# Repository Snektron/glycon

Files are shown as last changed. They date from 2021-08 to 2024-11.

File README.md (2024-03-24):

nin# Glycon

## Dependencies

* meson
* ninja or samurai
* avr-binutils
* avr-gcc
* avr-libc

## Compiling

### Coprocessor

```
$ mkdir -p build/glyco
$ cd build/glyco
$ meson ../.. --cross-file ../../cross/avr-atmega2560-cross.ini
$ ninja
```

To use the provided `flash` target to flash the coprocessor, set the coprocessor port the arduino is connected with by passing `-Dport=/dev/<port>` to meson (usually /dev/ttyUSB0) and add yourself to to appropriate groups (typically `dialout` or `uucp`).

### Debugger

```
$ mkdir -p build/glydb
$ cd build/glydb
$ meson ../..
$ ninja
```

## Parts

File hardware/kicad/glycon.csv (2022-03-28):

Source: | /home/florian/projecten/glycon/doc/kicad/glycon.kicad_sch
Date: | za 26 mrt 2022 12:57:02 CET
Tool: | Eeschema (6.99.0-588-g9b3e9082d3)
Generator: | /usr/share/kicad/plugins/bom_csv_grouped_by_value.py
Component Count: | 53
Individual Components:
Item | Qty | Reference(s) | Value | LibPart | Footprint | Datasheet | Allied Price/Stock | Allied_Number | Description | Height | Manufacturer_Name | Manufacturer_Part_Number | Mouser Part Number | Mouser Price/Stock | RS Part Number | RS Price/Stock
 |  | C1 | 100nF | Device:C | Capacitor_THT:C_Disc_D4.7mm_W2.5mm_P5.00mm | ~
 |  | C2 | 100nF | Device:C | Capacitor_THT:C_Disc_D4.7mm_W2.5mm_P5.00mm | ~
 |  | C3 | 100nF | Device:C | Capacitor_THT:C_Disc_D4.7mm_W2.5mm_P5.00mm | ~
 |  | C4 | 100nF | Device:C | Capacitor_THT:C_Disc_D4.7mm_W2.5mm_P5.00mm | ~
 |  | C5 | 100nF | Device:C | Capacitor_THT:C_Disc_D4.7mm_W2.5mm_P5.00mm | ~
 |  | C6 | 100nF | Device:C | Capacitor_THT:C_Disc_D4.7mm_W2.5mm_P5.00mm | ~
 |  | C7 | 100nF | Device:C | Capacitor_THT:C_Disc_D4.7mm_W2.5mm_P5.00mm | ~
 |  | C8 | 100nF | Device:C | Capacitor_THT:C_Disc_D4.7mm_W2.5mm_P5.00mm | ~
 |  | C9 | 100nF | Device:C | Capacitor_THT:C_Disc_D4.7mm_W2.5mm_P5.00mm | ~
 |  | C10 | 100nF | Device:C | Capacitor_THT:C_Disc_D4.7mm_W2.5mm_P5.00mm | ~
 |  | C11 | 100nF | Device:C | Capacitor_THT:C_Disc_D4.7mm_W2.5mm_P5.00mm | ~
 |  | C12 | 100nF | Device:C | Capacitor_THT:C_Disc_D4.7mm_W2.5mm_P5.00mm | ~
 |  | C13 | 100nF | Device:C | Capacitor_THT:C_Disc_D4.7mm_W2.5mm_P5.00mm | ~
 |  | D1 | LED | Device:LED | LED_THT:LED_D5.0mm | ~
 |  | H1 | MountingHole_Pad | Mechanical:MountingHole_Pad | MountingHole:MountingHole_3.2mm_M3_Pad | ~
 |  | H2 | MountingHole_Pad | Mechanical:MountingHole_Pad | MountingHole:MountingHole_3.2mm_M3_Pad | ~
 |  | H3 | MountingHole_Pad | Mechanical:MountingHole_Pad | MountingHole:MountingHole_3.2mm_M3_Pad | ~
 |  | H4 | MountingHole_Pad | Mechanical:MountingHole_Pad | MountingHole:MountingHole_3.2mm_M3_Pad | ~
 |  | H5 | MountingHole_Pad | Mechanical:MountingHole_Pad | MountingHole:MountingHole_3.2mm_M3_Pad | ~
 |  | J1 | Arduino/system bus header | Connector_Generic:Conn_02x20_Odd_Even | Connector_PinSocket_2.54mm:PinSocket_2x20_P2.54mm_Vertical | ~
 |  | J2 | PMOD USBUART conn | Connector_Generic:Conn_01x06 | Connector_PinHeader_2.54mm:PinHeader_1x06_P2.54mm_Vertical | ~
 |  | J3 | Conn_01x02 | Connector_Generic:Conn_01x02 | Connector_PinHeader_2.54mm:PinHeader_1x02_P2.54mm_Vertical | ~
 |  | J4 | Conn_02x24_Odd_Even | Connector_Generic:Conn_02x24_Odd_Even | Connector_PinSocket_2.54mm:PinSocket_2x24_P2.54mm_Vertical | ~
 |  | Q1 | IRF9540N | Transistor_FET:IRF9540N | Package_TO_SOT_THT:TO-220-3_Vertical | http://www.irf.com/product-info/datasheets/data/irf9540n.pdf
 |  | Q2 | IRF9540N | Transistor_FET:IRF9540N | Package_TO_SOT_THT:TO-220-3_Vertical | http://www.irf.com/product-info/datasheets/data/irf9540n.pdf
 |  | R1 | 10K | Device:R | Resistor_THT:R_Axial_DIN0204_L3.6mm_D1.6mm_P5.08mm_Horizontal | ~
 |  | R2 | 10K | Device:R | Resistor_THT:R_Axial_DIN0204_L3.6mm_D1.6mm_P5.08mm_Horizontal | ~
 |  | R3 | 10K | Device:R | Resistor_THT:R_Axial_DIN0204_L3.6mm_D1.6mm_P5.08mm_Horizontal | ~
 |  | R4 | 10K | Device:R | Resistor_THT:R_Axial_DIN0204_L3.6mm_D1.6mm_P5.08mm_Horizontal | ~
 |  | R5 | 10K | Device:R | Resistor_THT:R_Axial_DIN0204_L3.6mm_D1.6mm_P5.08mm_Horizontal | ~
 |  | R6 | 10K | Device:R | Resistor_THT:R_Axial_DIN0204_L3.6mm_D1.6mm_P5.08mm_Horizontal | ~
 |  | R7 | 10K | Device:R | Resistor_THT:R_Axial_DIN0204_L3.6mm_D1.6mm_P5.08mm_Horizontal | ~
 |  | R8 | 1K | Device:R | Resistor_THT:R_Axial_DIN0204_L3.6mm_D1.6mm_P5.08mm_Horizontal | ~
 |  | R9 | 10K | Device:R | Resistor_THT:R_Axial_DIN0204_L3.6mm_D1.6mm_P5.08mm_Horizontal | ~
 |  | R10 | 10K | Device:R | Resistor_THT:R_Axial_DIN0204_L3.6mm_D1.6mm_P5.08mm_Horizontal | ~
 |  | R11 | 10K | Device:R | Resistor_THT:R_Axial_DIN0204_L3.6mm_D1.6mm_P5.08mm_Horizontal | ~
 |  | R12 | 470 | Device:R | Resistor_THT:R_Axial_DIN0204_L3.6mm_D1.6mm_P5.08mm_Horizontal | ~
 |  | SW1 | SW_Push | Switch:SW_Push | Button_Switch_THT:SW_PUSH_6mm | ~
 |  | SW2 | SW_Push | Switch:SW_Push | Button_Switch_THT:SW_PUSH_6mm | ~
 |  | U0 | Z80CPU | CPU:Z80CPU | Package_DIP:DIP-40_W15.24mm_Socket | www.zilog.com/manage_directlink.php?filepath=docs/z80/um0080
 |  | U1 | 628128_DIP32_SSOP32 | Memory_RAM:628128_DIP32_SSOP32 | Package_DIP:DIP-32_W15.24mm_Socket | http://www.futurlec.com/Datasheet/Memory/628128.pdf
 |  | U2 | SST39SF010 | Memory_Flash:SST39SF010 | Package_DIP:DIP-32_W15.24mm_Socket | http://ww1.microchip.com/downloads/en/DeviceDoc/25022B.pdf
 |  | U3 | 74HC32 | 74xx:74LS32 | Package_DIP:DIP-14_W7.62mm_Socket | http://www.ti.com/lit/gpn/sn74LS32
 |  | U4 | 74HC04 | 74xx:74HC04 | Package_DIP:DIP-14_W7.62mm_Socket | https://assets.nexperia.com/documents/data-sheet/74HC_HCT04.pdf
 |  | U5 | 74LS21 | 74xx:74LS21 | Package_DIP:DIP-14_W7.62mm_Socket | http://www.ti.com/lit/gpn/sn74LS21
 |  | U6 | 74LS139 | 74xx:74LS139 | Package_DIP:DIP-16_W7.62mm_Socket | http://www.ti.com/lit/ds/symlink/sn74ls139a.pdf
 |  | U7 | SIO0-DIP-40 | Zilog_Z80_Peripherals:SIO0-DIP-40 | Package_DIP:DIP-40_W15.24mm_Socket | http://www.zilog.com/docs/z80/ps0183.pdf | https://www.alliedelec.com/zilog-z84c4206peg/R1000052/ | R1000052 | Z80 CMOS SIO/0 Z84C40 Zilog | 4.06 | Zilog | Z84C4206PEG | 692-Z84C4206PEG | https://www.mouser.com/Search/Refine.aspx?Keyword=692-Z84C4206PEG | 6600766 | https://uk.rs-online.com/web/p/products/6600766
 |  | U8 | PIO-DIP-40 | Zilog_Z80_Peripherals:PIO-DIP-40 | Package_DIP:DIP-40_W15.24mm_Socket | https://www.zilog.com/appnotes_download.php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
 |  | U9 | 74HC244 | 74xx:74HC244 | Package_DIP:DIP-20_W7.62mm_Socket | https://assets.nexperia.com/documents/data-sheet/74HC_HCT244.pdf
 |  | U10 | 74HC244 | 74xx:74HC244 | Package_DIP:DIP-20_W7.62mm_Socket | https://assets.nexperia.com/documents/data-sheet/74HC_HCT244.pdf
 |  | U11 | PIO-DIP-40 | Zilog_Z80_Peripherals:PIO-DIP-40 | Package_DIP:DIP-40_W15.24mm_Socket | https://www.zilog.com/appnotes_download.php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
 |  | U12 | CTC-DIP-28 | Zilog_Z80_Peripherals:CTC-DIP-28 | Package_DIP:DIP-28_W15.24mm_Socket | http://www.zilog.com/docs/z80/ps0181.pdf |  |  | Z8430 Zilog CTC | 5.21 | Zilog | Z84C3010PEG | 692-Z84C3010PEG | https://www.mouser.com/Search/Refine.aspx?Keyword=692-Z84C3010PEG
 |  | X1 | ACO-6.144MHz | Oscillator:ACO-xxxMHz | Oscillator:Oscillator_DIP-14 | http://www.conwin.com/datasheets/cx/cx030.pdf
Collated Components:
Item | Qty | Reference(s) | Value | LibPart | Footprint | Datasheet | Allied Price/Stock | Allied_Number | Description | Height | Manufacturer_Name | Manufacturer_Part_Number | Mouser Part Number | Mouser Price/Stock | RS Part Number | RS Price/Stock
1 | 13 | C1, C2, C3, C4, C5, C6, C7, C8, C9, C10, C11, C12, C13 | 100nF | Device:C | Capacitor_THT:C_Disc_D4.7mm_W2.5mm_P5.00mm | ~
2 | 1 | D1 | LED | Device:LED | LED_THT:LED_D5.0mm | ~
3 | 5 | H1, H2, H3, H4, H5 | MountingHole_Pad | Mechanical:MountingHole_Pad | MountingHole:MountingHole_3.2mm_M3_Pad | ~
4 | 1 | J1 | Arduino/system bus header | Connector_Generic:Conn_02x20_Odd_Even | Connector_PinSocket_2.54mm:PinSocket_2x20_P2.54mm_Vertical | ~
5 | 1 | J2 | PMOD USBUART conn | Connector_Generic:Conn_01x06 | Connector_PinHeader_2.54mm:PinHeader_1x06_P2.54mm_Vertical | ~
6 | 1 | J3 | Conn_01x02 | Connector_Generic:Conn_01x02 | Connector_PinHeader_2.54mm:PinHeader_1x02_P2.54mm_Vertical | ~
7 | 1 | J4 | Conn_02x24_Odd_Even | Connector_Generic:Conn_02x24_Odd_Even | Connector_PinSocket_2.54mm:PinSocket_2x24_P2.54mm_Vertical | ~
8 | 2 | Q1, Q2 | IRF9540N | Transistor_FET:IRF9540N | Package_TO_SOT_THT:TO-220-3_Vertical | http://www.irf.com/product-info/datasheets/data/irf9540n.pdf
9 | 10 | R1, R2, R3, R4, R5, R6, R7, R9, R10, R11 | 10K | Device:R | Resistor_THT:R_Axial_DIN0204_L3.6mm_D1.6mm_P5.08mm_Horizontal | ~
10 | 1 | R8 | 1K | Device:R | Resistor_THT:R_Axial_DIN0204_L3.6mm_D1.6mm_P5.08mm_Horizontal | ~
11 | 1 | R12 | 470 | Device:R | Resistor_THT:R_Axial_DIN0204_L3.6mm_D1.6mm_P5.08mm_Horizontal | ~
12 | 2 | SW1, SW2 | SW_Push | Switch:SW_Push | Button_Switch_THT:SW_PUSH_6mm | ~
13 | 1 | U0 | Z80CPU | CPU:Z80CPU | Package_DIP:DIP-40_W15.24mm_Socket | www.zilog.com/manage_directlink.php?filepath=docs/z80/um0080
14 | 1 | U1 | 628128_DIP32_SSOP32 | Memory_RAM:628128_DIP32_SSOP32 | Package_DIP:DIP-32_W15.24mm_Socket | http://www.futurlec.com/Datasheet/Memory/628128.pdf
15 | 1 | U2 | SST39SF010 | Memory_Flash:SST39SF010 | Package_DIP:DIP-32_W15.24mm_Socket | http://ww1.microchip.com/downloads/en/DeviceDoc/25022B.pdf
16 | 1 | U3 | 74HC32 | 74xx:74LS32 | Package_DIP:DIP-14_W7.62mm_Socket | http://www.ti.com/lit/gpn/sn74LS32
17 | 1 | U4 | 74HC04 | 74xx:74HC04 | Package_DIP:DIP-14_W7.62mm_Socket | https://assets.nexperia.com/documents/data-sheet/74HC_HCT04.pdf
18 | 1 | U5 | 74LS21 | 74xx:74LS21 | Package_DIP:DIP-14_W7.62mm_Socket | http://www.ti.com/lit/gpn/sn74LS21
19 | 1 | U6 | 74LS139 | 74xx:74LS139 | Package_DIP:DIP-16_W7.62mm_Socket | http://www.ti.com/lit/ds/symlink/sn74ls139a.pdf
20 | 1 | U7 | SIO0-DIP-40 | Zilog_Z80_Peripherals:SIO0-DIP-40 | Package_DIP:DIP-40_W15.24mm_Socket | http://www.zilog.com/docs/z80/ps0183.pdf | https://www.alliedelec.com/zilog-z84c4206peg/R1000052/ | R1000052 | Z80 CMOS SIO/0 Z84C40 Zilog | 4.06 | Zilog | Z84C4206PEG | 692-Z84C4206PEG | https://www.mouser.com/Search/Refine.aspx?Keyword=692-Z84C4206PEG | 6600766 | https://uk.rs-online.com/web/p/products/6600766
21 | 2 | U8, U11 | PIO-DIP-40 | Zilog_Z80_Peripherals:PIO-DIP-40 | Package_DIP:DIP-40_W15.24mm_Socket | https://www.zilog.com/appnotes_download.php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
22 | 2 | U9, U10 | 74HC244 | 74xx:74HC244 | Package_DIP:DIP-20_W7.62mm_Socket | https://assets.nexperia.com/documents/data-sheet/74HC_HCT244.pdf
23 | 1 | U12 | CTC-DIP-28 | Zilog_Z80_Peripherals:CTC-DIP-28 | Package_DIP:DIP-28_W15.24mm_Socket | http://www.zilog.com/docs/z80/ps0181.pdf |  |  | Z8430 Zilog CTC | 5.21 | Zilog | Z84C3010PEG | 692-Z84C3010PEG | https://www.mouser.com/Search/Refine.aspx?Keyword=692-Z84C3010PEG
24 | 1 | X1 | ACO-6.144MHz | Oscillator:ACO-xxxMHz | Oscillator:Oscillator_DIP-14 | http://www.conwin.com/datasheets/cx/cx030.pdf

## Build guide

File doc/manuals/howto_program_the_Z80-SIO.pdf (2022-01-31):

Mario Blunk / electronics and IT engineering Buchfinkenweg 5
99102 Erfurt
Germany

cellular +49 (0)176 2904 5855 office phone +49 (0361) 5189 618
email | marioblunk@arcor.de
homepage | http://www.trainz.de (http://www.train-z.de/)

How To Program The Z80 Serial I/O (SIO) and CTC Document Version 2.1

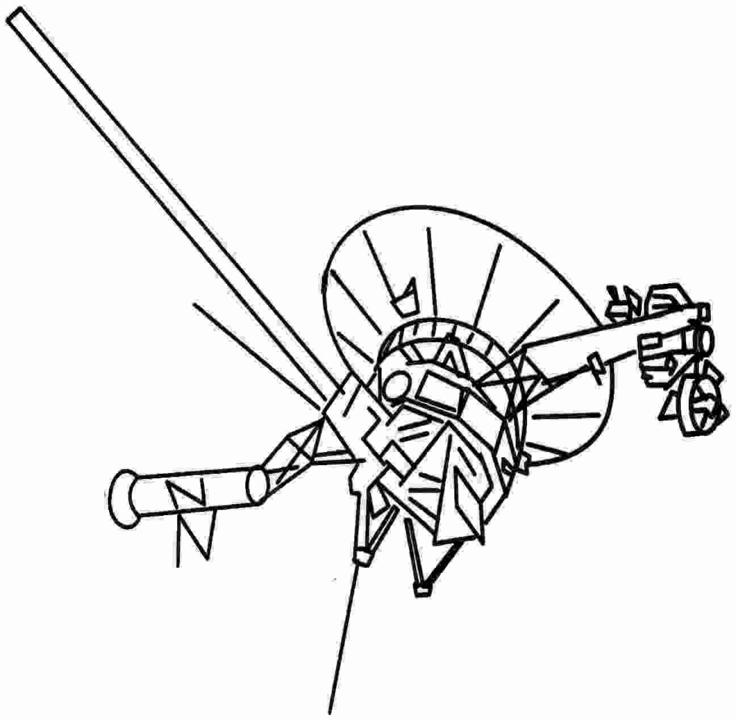
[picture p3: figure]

Date: 2010-03-31

## Contents

### Preface

The Z80 SIO is the most powerful I/O device of the Z80 product family. The official ZiLOG-datasheet gives a good overall view of all the features of this device but lacks a tutorial like approach and programming examples in assembly language.

This document aims to make the Z80 processor system popular again since a lot of valuable literature and expertise has vanished from the public because of more sophisticated processor architectures of the present.

Remarkably ZiLOG still produces the ICs of the Z80 family – since the late seventies !

Part one of this document describes how to program the SIO so that it communicates with a PC in asynchronous terminal mode whereas part two focuses on the block transfer mode used for file transmission. Also slightly touched in this document is the CTC programming and implementation of an interrupt mechanism.

There is no special focus on hardware issues like device selection, pin characteristics or ratings. Please refer to the official ZiLOG datasheets at www.zilog.com or www.z80.info .

The code examples shown here provide by far not the best performance and robustness. Therefore I appreciate every hint or critics to improve the quality of this document.

## 1 Terminal Mode

### 1.1 Desired Communication Mechanism

We want to program the SIO for asynchronous RS232 terminal mode with these parameters:
Baudrate: | 9600 Baud/sec
Stopbits: | 1
Startbits: | 1
Character length: 8 bit
Parity: none

In terminal mode the host computer (in our case the PC with any terminal program like Minicom or Hyper Terminal and an RS232 interface) communicates with the client (the Z80-SIO) character based via a so called Null-Modem-Cable. The host transmits one or more characters to the client, whereupon the client echoes this character back to the host and processes it. The host displays the echoed character on its screen. If the host does not “hear” the echoed character the communication is faulty.

Special attention is to be paid to the flow control scheme which is hardware based. In general this is called “RTSCTS” or just “hardware flow control”. This method allows transmission of all 8-bitcharacters (so called binary mode) and prevents overrunning of one of the peers in case on of them is to slow. In this document I assume the host PC is much faster than the client.
The wiring of the null modem cable used here has following connections between its female 9 pin D-Sub connectors:
1 – 4 / 4-1 | cross wired DTR and DCD
2 – 3 / 3 – 2 | cross wired TxD and RxD
5 – 5 | signal ground (GND)
7 – 8 / 8 – 7 | cross wird RTC and CTS
9 – 9 | ring indicator (RI, not used here)

### 1.2 SIO Device Structure and external wiring

Figure 1 shows the block diagram of the device with the blocks and signals needed for our example outlined in red. Figure 2 shows the data paths within the SIO. Marked in red are the blocks we need for asynchronous mode.

### 1.2.1 Wiring

Data and control: | These are the Z80 bus signals D[7:0], A[1:0], /RD, /IOREQ,
/RESET, /CE and CLK.

Interrupt Control Lines: /M1, /INT connected to CPU, IEI and IEO daisy chained to other periphery

Serial Data: | TxD and RxD going towards host computer¹
Channel Clocks: | TxCA and RxCA driven by CTC channel output TO0

Modem or other Controls: CTS, RTS, DTR, DCD used for hardware flow control

miscellaneous: | /SYNC not used, pulled high by 10k resistor
/Wait/Ready comes out of the device. It is to be connected to the WAIT-Input of the Z80-CPU. By asserting this signal the SIO tells the CPU to wait until the SIO has completed a character transfer. For this example we do not make use of this connection.

1 Usually these signals are not connected directly to the host but via diver devices like MAX232, 1488, 1489 or similar level converters.

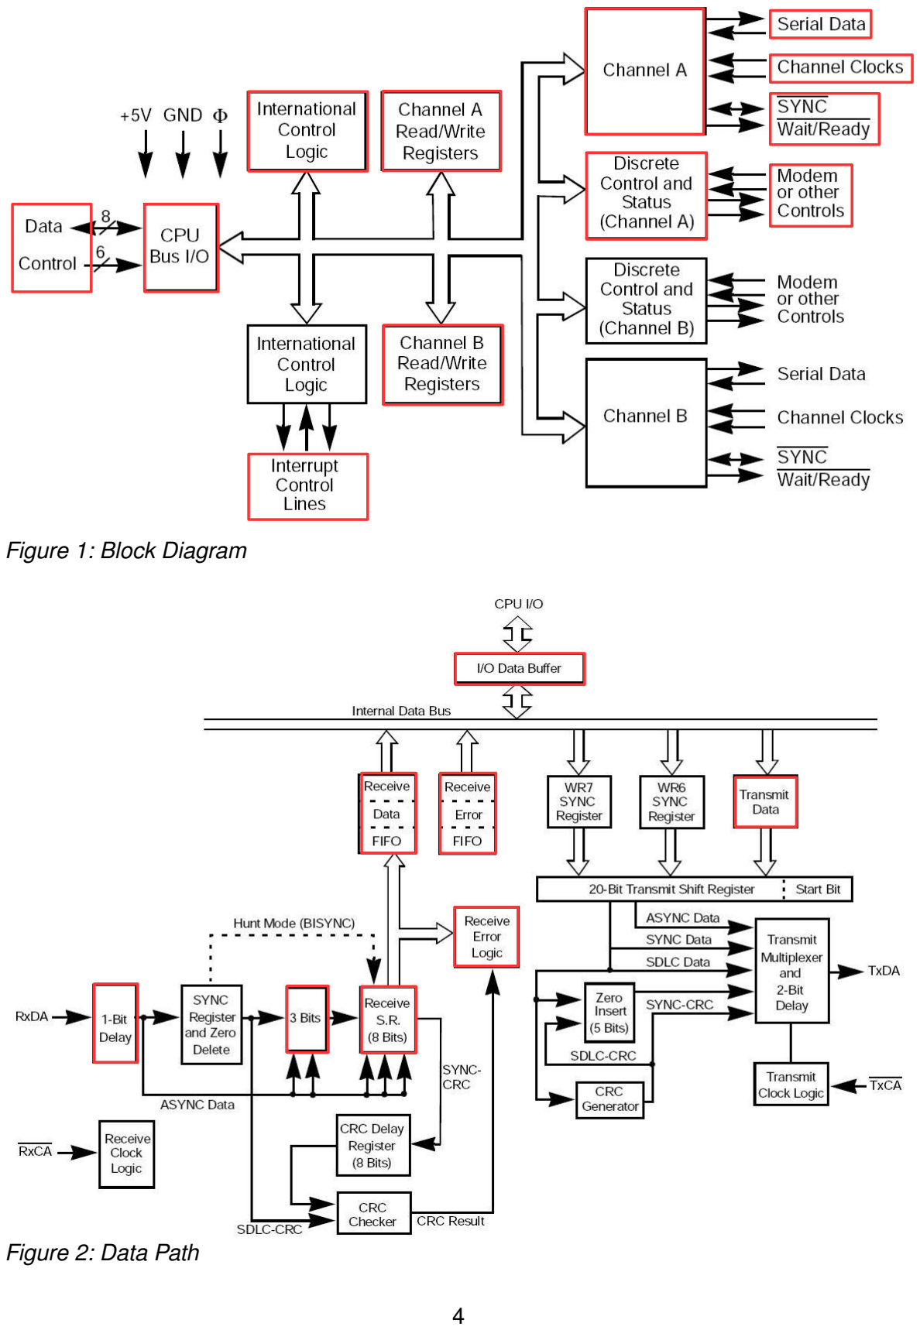
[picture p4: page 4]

Figure 1: Block Diagram

Figure 2: Data Path

### 1.3 Programming

Tree problems have to be solved: initializing the SIO, implementing the interrupt mechanism, echoing the received character, transmitting a character and turning on/off the SIO RX-channel in certain situations.

### 1.3.1 Header

The header show below defines the hardware addresses of the data and control port of your SIO and the address of your CTC channel 0. My hardware here uses the addresses 0x4, 0x6 and 0x0.

### 1.3.2 Interrupt Vector Table

Every time the SIO receives a character it requests an interrupt causing the CPU to jump to the memory address specified by the term RX_CHA_AVAILABLE. Special receive conditions like receiver buffer overrun cause a jump to location SPEC_RX_CONDITION.

Text 1: header

SIO_A_D | equ | 4h
SIO_A_C | equ | 6h
CH0 | equ | 0h

Text 2: SIO interrupt vector table

INT_VEC:
org | 0Ch
DEFW | RX_CHA_AVAILABLE
org | 0Eh
DEFW | SPEC_RX_CONDITON

### 1.3.3 Initializing the SIO

First we have to configure the SIO using the sequence shown in Text 3. For detailed information on the purpose of certain registers and control bits please read the SIO datasheet. We operate the SIO in interrupt mode “interrupt on all received characters”.

Text 3: configure the SIO

SIO_A_RESET:
;set up TX and RX:
ld | a,00110000b | ;write into WR0: error reset, select WR0
out | (SIO_A_C),A
ld | a,018h | ;write into WR0: channel reset
out | (SIO_A_C),A
ld | a,004h | ;write into WR0: select WR4
out | (SIO_A_C),A
ld | a,44h | ;44h write into WR4: clkx16,1 stop bit, no parity
out | (SIO_A_C),A
ld | a,005h | ;write into WR0: select WR5
out | (SIO_A_C),A
ld | a,0E8h | ;DTR active, TX 8bit, BREAK off, TX on, RTS inactive
out | (SIO_A_C),A
ld | a,01h | ;write into WR0: select WR1
out | (SIO_B_C),A
ld | a,00000100b | ;no interrupt in CH B, special RX condition affects vect
out | (SIO_B_C),A
ld | a,02h | ;write into WR0: select WR2
out | (SIO_B_C),A
ld | a,0h | ;write into WR2: cmd line int vect (see int vec table)
| | ;bits D3,D2,D1 are changed according to RX condition
out | (SIO_B_C),A
ld | a,01h | ;write into WR0: select WR1
out | (SIO_A_C),A
ld | a,00011000b | ;interrupt on all RX characters, parity is not a spec RX condition
| | ;buffer overrun is a spec RX condition
out | (SIO_A_C),A

SIO_A_EI:
;enable SIO channel A RX
ld | a,003h | ;write into WR0: select WR3
out | (SIO_A_C),A
ld | a,0C1h | ;RX 8bit, auto enable off, RX on
out | (SIO_A_C),A
;Channel A RX active
RET

### 1.3.4 Initializing the CTC

The CTC channel 0 provides the receive and transmit clock for the SIO.

### 1.3.5 Initializing the CPU

The CPU is to run in interrupt mode 2. See Text 5 below. This has to be done after initializing SIO and CTC.

Text 5: set up the CPU interrupt mode 2

INT_INI:
ld | A,0
ld | I,A | ;load I reg with zero
im | 2 | ;set int mode 2
ei | | ;enable interupt

Text 4: configuring the CTC channel 0

INI_CTC:

;init CH0
;CH0 provides SIO A RX/TX clock
ld | A,00000111b | ; int off, timer on, prescaler=16, don't care ext. TRG edge,
| | ; start timer on loading constant, time constant follows
| | ; swrst active, this is a ctrl cmd
out | (CH0),A
ld | A,2h | ; time constant defined
out | (CH0),A | ; and loaded into channel 0
| | ; TO0 outputs frequency=CLK/2/16/(time constant)/2
| | ; which results in 9600 bits per sec

### 1.3.6 Hardware Flow Control

In order to signal the host whether the client is ready or not to receive a character the RTS line coming out of the client (and driving towards the host) needs to be switched. As earlier said I assume the host is much faster than the client, that why I do not implement a routine to check the CTS-line coming from the host.

### 1.3.7 Disabling SIO RX-channel

When certain conditions arise it might by important to disable the receive channel of the SIO (see routine in Text 7).

Text 6: signaling the host go or nogo for reception

A_RTS_OFF:
ld | a,005h | ;write into WR0: select WR5
out | (SIO_A_C),A
ld | a,0E8h | ;DTR active, TX 8bit, BREAK off, TX on, RTS inactive
out | (SIO_A_C),A
ret

A_RTS_ON:
ld | a,005h | ;write into WR0: select WR5
out | (SIO_A_C),A
ld | a,0EAh | ;DTR active, TX 8bit, BREAK off, TX on, RTS active
out | (SIO_A_C),A
ret

Text 7: Disabling the SIO

SIO_A_DI:
;disable SIO channel A RX
ld | a,003h | ;write into WR0: select WR3
out | (SIO_A_C),A
ld | a,0C0h | ;RX 8bit, auto enable off, RX off
out | (SIO_A_C),A
;Channel A RX inactive
ret

### 1.3.8 Interrupt Service Routines

Upon reception of a character the routine RX_CHA_AVAILABLE shown in Text 8 is executed. Here you get the character set by the host. In the end of this routine, the character is sent back to the host by a simple single command
out (SIO_A_D),A
Note: In this example we backup only register AF. Depending on your application you might be required to backup more registers like HL, DE, CD, ...
Routine SPEC_RX_CONDITION is executed upon a special receive condition like buffer overrun. In my example the CPU is to jump at the warmstart location 0x0000.

Note: The code written in red might be required if you want the CPU to be ready for another interrupt (ei) and to give the host a go for another transmission (call A_RTS_ON). I recommend to put these two lines not here but in your main program routine that processes the characters received by the SIO. This way you process one character after another and avoid overrunning your SIO RX buffer.

Text 8: character received routine

RX_CHA_AVAILABLE:

push | AF | ;backup AF
call | A_RTS_OFF
in | A,(SIO_A_D) | ;read RX character into A

; A holds received character

;do something with the received character

;echo character to host
out | (SIO_A_D),A
call | TX_EMP
ei | | ;see comments below
call | A_RTS_ON | ;see comments below
pop | AF | ;restore AF
Reti

SPEC_RX_CONDITON:
jp 0000h

### 1.3.9 Transmission of a character to the host

In general transmitting of a character is done by the single command
out (SIO_A_D),A
as written in Text 8. To make sure the character has been sent completely the transmit buffer needs to be checked if it is empty. The general routine to achieve this is shown in Text 9.

Text 9: transmitting a character to host

TX_EMP:
; check for TX buffer empty
sub | a | ;clear a, write into WR0: select RR0
inc | a | ;select RR1
out | (SIO_A_C),A
in | A,(SIO_A_C) | ;read RRx
bit | 0,A
jp | z,TX_EMP
ret

## 2 File Transfer Mode

### 2.1 Desired Communication Mechanism

We want to program the SIO for asynchronous RS232 X-Modem protocol with these parameters:

Baudrate: | 9600 Baud/sec
Stopbits: | 1
Startbits: | 1
Character length: 8 bit
Parity: none

In difference to the character based mode described in part 1 (Terminal Mode) blocks of 128 byte size are to be transferred over the Null-Modem-Cable from the host PC to the client, the Z80-machine. I choose the X-Modem protocol due to its robustness and easy feasibility. Typical terminal programs like HyperTerminal, Kermit or Minicom do support the X-Modem protocol.
Of course you can also transfer a file via character based mode but the transfer will take much more time.
Regarding the device structure, Null-Modem-Cable, wiring and flowcontrol please refer to section 1.1 on page 2 and 1.2 on page 3.

A web link to the description of the X-Modem protocol can be found in section 4 on page 19.

Note: For this mode the connection of the CPU pin /WAIT and the SIO pin /Wait/Ready is required. Please see section 1.2.1 on page 3.

### 2.2 Programming

Four problems have to be solved: initializing the SIO, implementing the interrupt mechanism, requesting the host to start the X-Modem transfer and load the file to a certain RAM location.

### 2.2.1 Header

The header show below defines the hardware addresses of the data and control port of your SIO and the address of your CTC channel 0. My hardware here uses the addresses 0x4, 0x6 and 0x0. Further on there is a RAM locations defined for counting bad blocks while the file is being transferred.

### 2.2.2 Interrupt Vector Table

Every time the SIO receives the first byte of a block it requests an interrupt causing the CPU to jump to the memory address specified by the term BYTE_AVAILABLE. This is the interrupt mode: interrupt on first character. Special receive conditions like receiver buffer overrun cause a jump to location SPEC_BYTE_COND. The latter case aborts the transfer.

### 2.2.3 Initializing the CTC

Please read section 1.3.4 on page 7.

Text 10: header

SIO_A_D | equ | 4h
SIO_A_C | equ | 6h
CH0 | equ | 0h
temp0 | equ | 1015h ;holds number of
| | ;unsuccessful block transfers/block during download

Text 11: SIO interrupt vector table

INT_VEC:
org | 1Ch
DEFW | BYTE_AVAILABLE
org | 1Eh
DEFW | SPEC_BYTE_COND

### 2.2.4 Initializing the CPU

Please read section 1.3.5 on page 7.

### 2.2.5 X-Modem File Transfer

The assembly code of this module is described in the following sections. Due to its complexity I split it into parts shown in Text 12, 13 and 14 whose succession must not be mixed. For detailed information on the purpose of certain registers and control bits please read the SIO datasheet.

### 2.2.5.1 Host triggered transfer and setup

The host PC initiates the transfer. Using Minicom for example you press CTRL-A-S to get into a menu where you select the xmodem protocol and afterward into the file menu to select the file to be sent to the client. The procedure is similar with HyperTerminal.
After that the host waits for a NAK character sent by the client.
Now you should run the code shown below in Text 12 on your Z80-machine. This code initializes the SIO for interrupt mode “interrupt on first received character”.

;set up TX and RX:

ld | a,018h | ;write into WR0: channel reset
out | (SIO_A_C),A
ld | a,004h | ;write into WR0: select WR4
out | (SIO_A_C),A
ld | a,44h | ;44h write into WR4: clkx16,1 stop bit, no parity
out | (SIO_A_C),A
ld | a,005h | ;write into WR0: select WR5
out | (SIO_A_C),A
ld | a,0E8h | ;DTR active, TX 8bit, BREAK off, TX on, RTS inactive
out | (SIO_A_C),A
ld | a,01h | ;write into WR0: select WR1
out | (SIO_B_C),A
ld | a,00000100b | ;no interrupt in CH B, special RX condition affects vect
out | (SIO_B_C),A
ld | a,02h | ;write into WR0: select WR2
out | (SIO_B_C),A
ld | a,10h | ;write into WR2: cmd line int vect (see int vec table)
out | (SIO_B_C),A | ;bits D3,D2,D1 are changed according to RX condition

Text 12: setup 1

Now we do some settings for bad block counting, the first block number to expect and the RAM destination address of the file to receive from the host. See Text 13. The destination address setting is red colored. From this RAM location onwards the file is to be stored. Im my example I use address 0x8000. Depending on your application you should change this value.

Text 14 shows the code section that prepares the CPU for the reception of the first byte of a data block. The line colored red makes the CPU waiting for an interrupt which is caused by the SIO. The belonging interrupt service routine is shown in Text 15.
Once a block has been received, the checksum is verified and possible bad blocks counted. The same data block is transferred maximal 10 times whereupon the transfer is aborted.
sub | A
ld | (temp0),A | ;reset bad blocks counter
ld | C,1h | ;C holds first block nr to expect
ld | HL,8000h | ;set lower destination address of file
call | SIO_A_EI
call | A_RTS_ON
call | TX_NAK | ;NAK indicates ready for transmission to host

Text 13: setup 2

REC_BLOCK:

;set block transfer mode
ld | a,21h | ;write into WR0 cmd4 and select WR1
out | (SIO_A_C),A
ld | a,10101000b | ;wait active, interrupt on first RX character
out | (SIO_A_C),A | ;buffer overrun is a spec RX condition

ei
call | A_RTS_ON
halt | | ;await first rx char
call | A_RTS_OFF
ld | a,01h | ;write into WR0: select WR1
out | (SIO_A_C),A
ld | a,00101000b | ;wait function inactive
out | (SIO_A_C),A

;check return code of block reception (e holds return code)
ld | a,e
cp | 0 | ;block finished, no error
jp | z,l_210
cp | 2 | ;eot found
jp | z,l_211
cp | 3 | ;chk sum error
jp | z,l_613
ld | a,10h
jp | l_612
l_210: call | TX_ACK | ;when no error
inc | c | ;prepare next block to receive
sub | A
ld | (temp0),A | ;clear bad block counter
jp | REC_BLOCK
l_211: call | TX_ACK | ;on eot
ld | A,01h
jp | l_612
l_613: call | TX_NAK | ;on chk sum error
scf
ccf | | ;clear carry flag
ld | DE,0080h | ;subtract 80h
sbc | HL,DE | ;from HL, so HL is reset to block start address
ld | A,(temp0) | ;count bad blocks in temp0
inc | A
ld | (temp0),A
cp | 09h
jp | z,l_612 | ;abort download after 9 attempts to transfer a block
jp | REC_BLOCK | ;repeat block reception

l_612:
DLD_END:

ret

Text 14: Receive Data Block

BYTE_AVAILABLE:

EXP_SOH_EOT:
| in | A,(SIO_A_D) | ;read RX byte into A
l_205: cp | 01h | ;check for SOH
| jp | z,EXP_BLK_NR
| cp | 04h | ;check for EOT
| jp | nz,l_2020
| ld | e,2h
| reti

;await block number
EXP_BLK_NR:
| in | A,(SIO_A_D) | ;read RX byte into A
| cp | C | ;check for match of block nr
| jp | nz,l_2020

;await complement of block number
| ld | A,C | ;copy block nr to expect into A
| CPL | | ;and cpl A
| ld | E,A | ;E holds cpl of block nr to expect

EXP_CPL_BLK_NR:
| in | A,(SIO_A_D) | ;read RX byte into A
| cp | E | ;check for cpl of block nr
| jp | nz,l_2020

;await data block
| ld | D,0h | ;start value of checksum
| ld | B,80h | ;defines block size 128byte

EXP_DATA:
| in | A,(SIO_A_D) | ;read RX byte into A
| ld | (HL),A
| add | A,D | ;update
| ld | D,A | ;checksum in D
| inc | HL | ;dest address +1
| djnz | EXP_DATA | ;loop until block finished

EXP_CHK_SUM:
| in | A,(SIO_A_D) | ;read RX byte into A
; | ld | a,045h | ;for debug only
| cp | D | ;check for checksum match
| jp | z,l_2021
| ld | e,3h
| reti
l_2020: ld | E,1h
| RETI
l_2021: ld | E,0h
| RETI | | ;return when block received completely

;-Int routine on RX overflow

SPEC_BYTE_COND: | ;in case of RX overflow prepare abort of transfer
| ld | HL,DLD_END
| push | HL
| reti

Text 15: Interrupt Service Routine

### 2.2.5.2 Subroutines

Important for the X-Modem protocol is the sending of the Acknowledge and the Not-Acknowledge character to the host machine. For all other routines used in the code above please refer to sections 1.3.3 on page 6 and 1.3.6 on page 8.

TX_NAK:
ld | a,15h | ;send NAK 15h to host
out | (SIO_A_D),A
call | TX_EMP
RET

TX_ACK:
ld | a,6h | ;send AK to host
out | (SIO_A_D),A
call | TX_EMP
RET

Text 16: Acknowledge / Not-Acknowledge

## 3 Z80 IC equivalents table

An overview of ICs of the famous Z80 family gives Table 1.

device | equivalent type
Z80-CPU | BU18400A-PS (ROHM) D780C-1(NEC) KP1858BM1/2/3 / KR1858BM1/2/3 (USSR) LH0080 (Sharp) MK3880x (Mostek) T34VM1 / T34BM1 (USSR) TMPZ84C00AP-8 (Toshiba) UA880 / UB880 / VB880D (MME) Z0840004 (ZiLOG) Z0840006 (ZiLOG) Z80ACPUD1 (SGS-Ates) Z84C00AB6 (SGS-Thomson) Z84C00 (ZiLOG) Z8400A (Goldstar) U84C00 (MME)
Z80-SIO | UA8560 , UB8560 (MME) Z0844004 (ZiLOG) Z8440AB1 (ST) Z0844006 (ZiLOG) Z84C40 (ZiLOG) U84C40 (MME)
Z80-PIO | Z0842004/6 (ZiLOG) UA855 / UB855 (MME) Z84C20 (ZiLOG) U84C20 (MME)
Z80-CTC | Z84C30 (ZiLOG) U84C30 (MME) UA857 / UB857 (MME)

Table 1: Z80 equivalents

## 4 Useful Links

A complete embedded Z80 system can be found at http://www.trainz.de/trainz (http://www.train-z.de/train-z)

The Free and Open Productivity Suite OpenOffice at http://www.openoffice.org Z80 assembler for Linux and UNIX at http://www.unix4fun.org/z80pack/
The powerful communication tool Kermit at http://www.columbia.edu/kermit/ The Z80 history at http://en.wikipedia.org/wiki/Zilog_Z80
The X-Modem Protocol Reference
at http://www.trainz. de/trainz/pdf/xymodem.pdf (http://www.trainz.de/trainz/pdf/xymodem.pdf)

EAGLE an affordable and very efficient schematics and layout tool at http://www.cadsoftusa.com/

## 5 Further Reading

I recommend to read these books:

“Using C-Kermit” / Frank da Cruz, Christine M. Gianone /
ISBN 1-55558-108-0 (english)
“C-Kermit : Einführung und Referenz” / Frank da Cruz, Christine M. Gianone / ISBN 3-88229-023-4 (german)

## 6 Disclaimer

This tutorial is believed to be accurate and reliable. I do not assume responsibility for any errors which may appear in this document. I reserve the right to change it at any time without notice, and do not make any commitment to update the information contained herein.
My Boss is a Jewish Carpenter

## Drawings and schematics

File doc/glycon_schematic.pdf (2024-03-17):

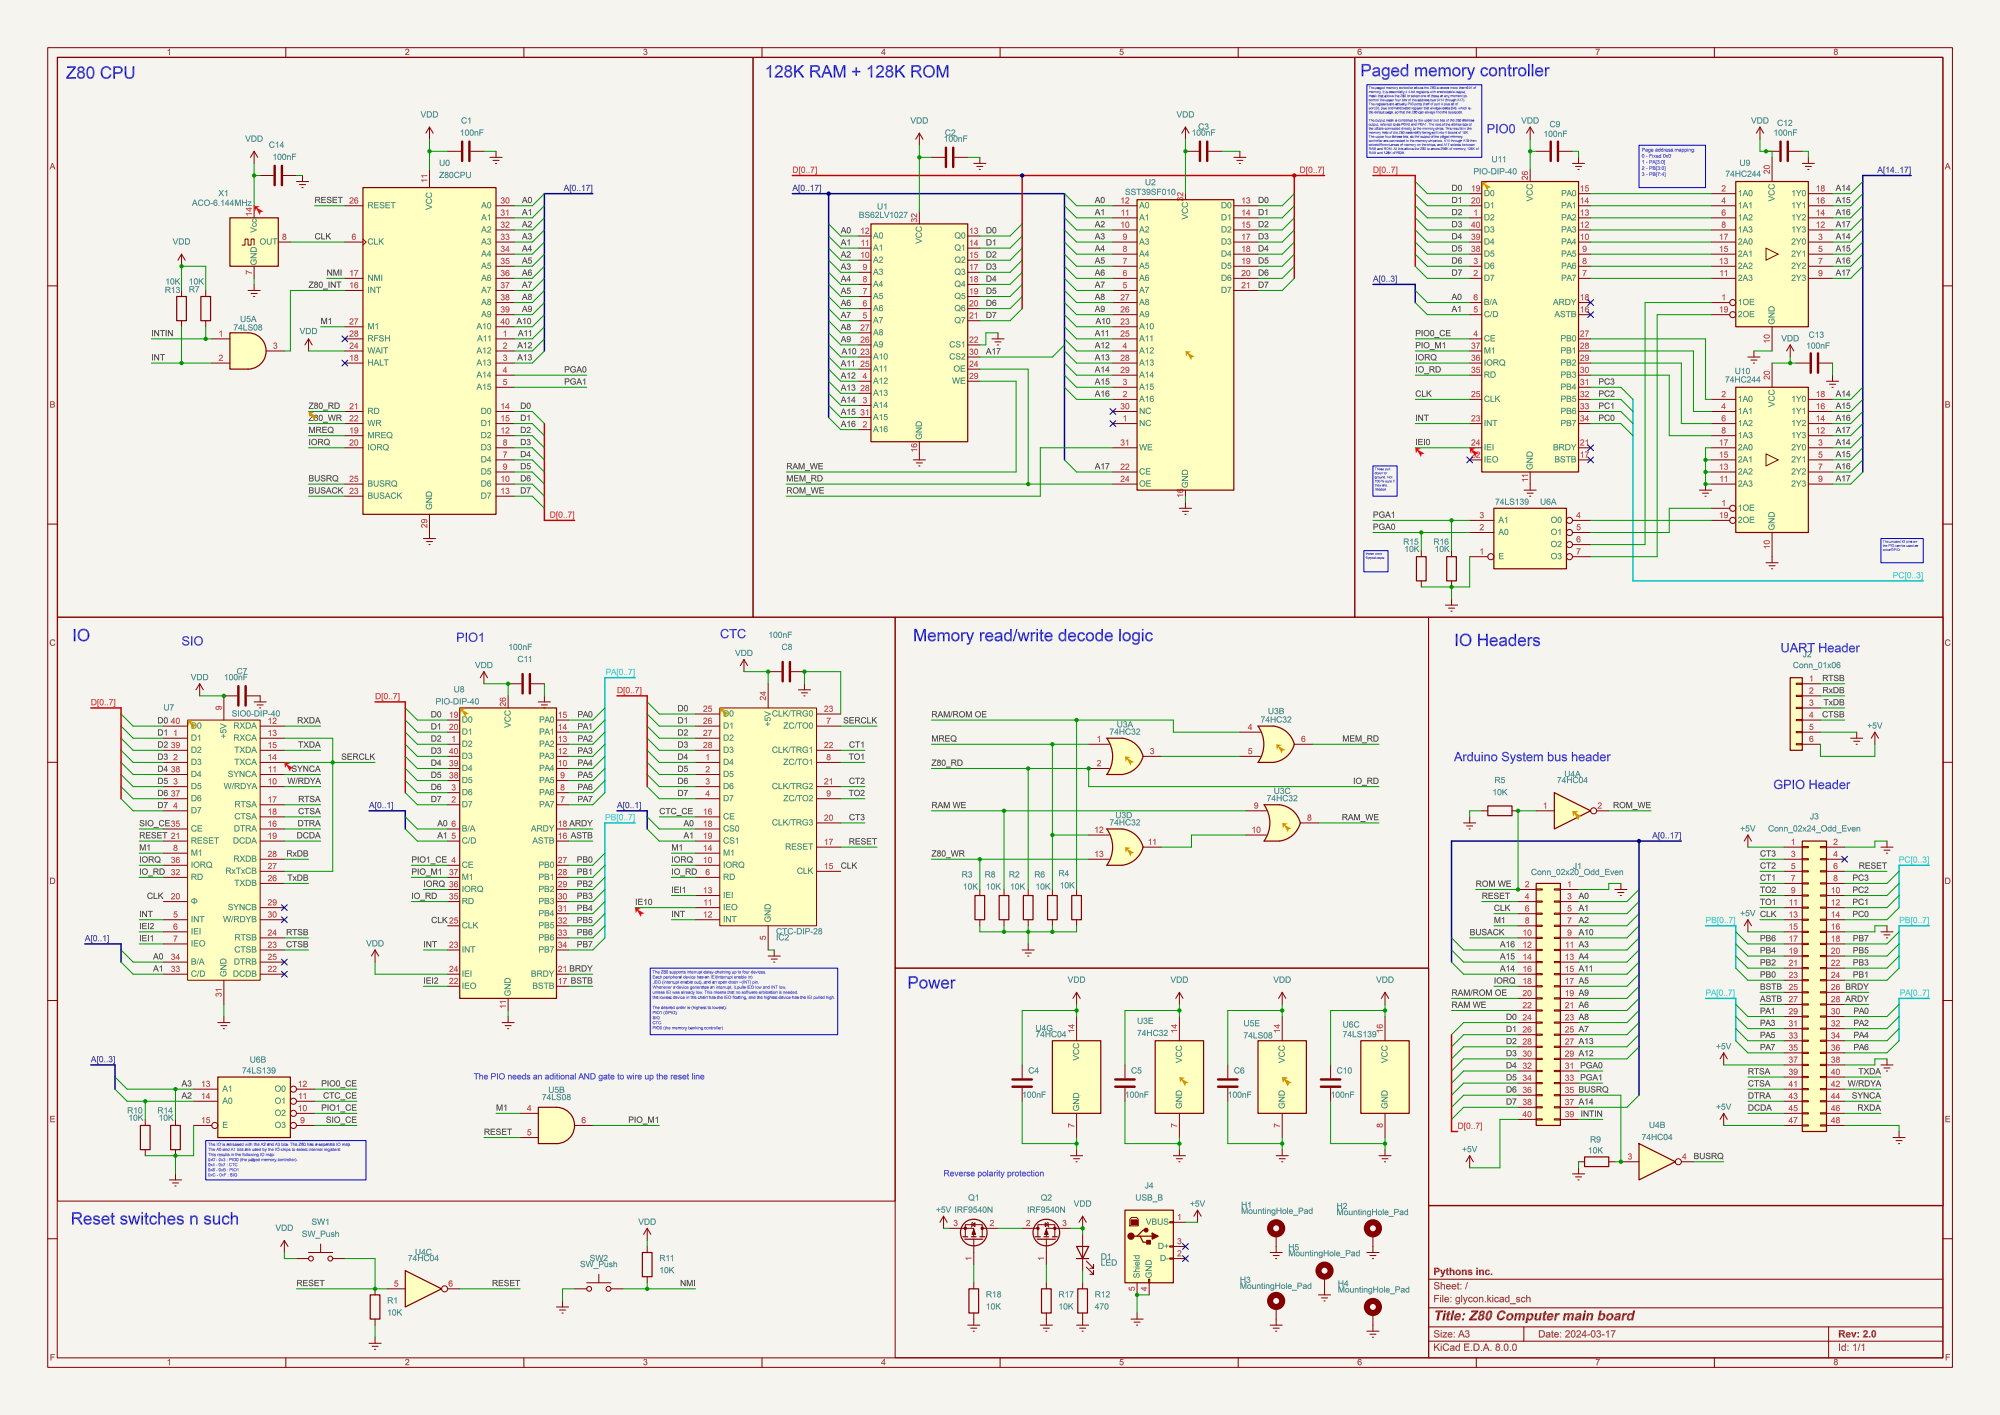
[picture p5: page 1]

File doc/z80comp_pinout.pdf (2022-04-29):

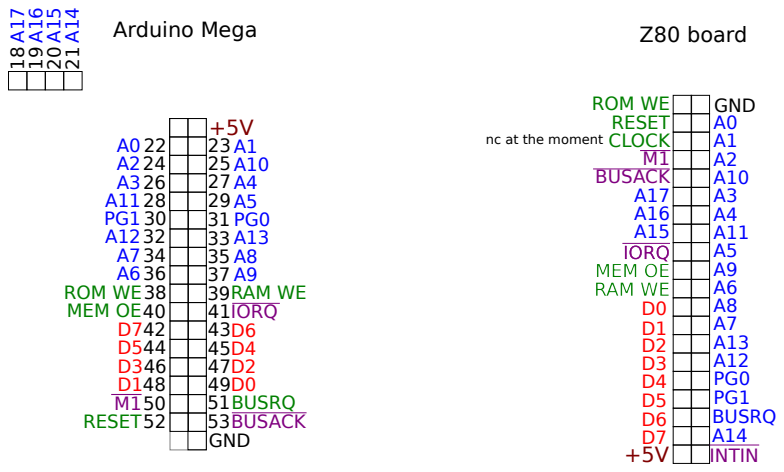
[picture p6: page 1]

nc at the moment

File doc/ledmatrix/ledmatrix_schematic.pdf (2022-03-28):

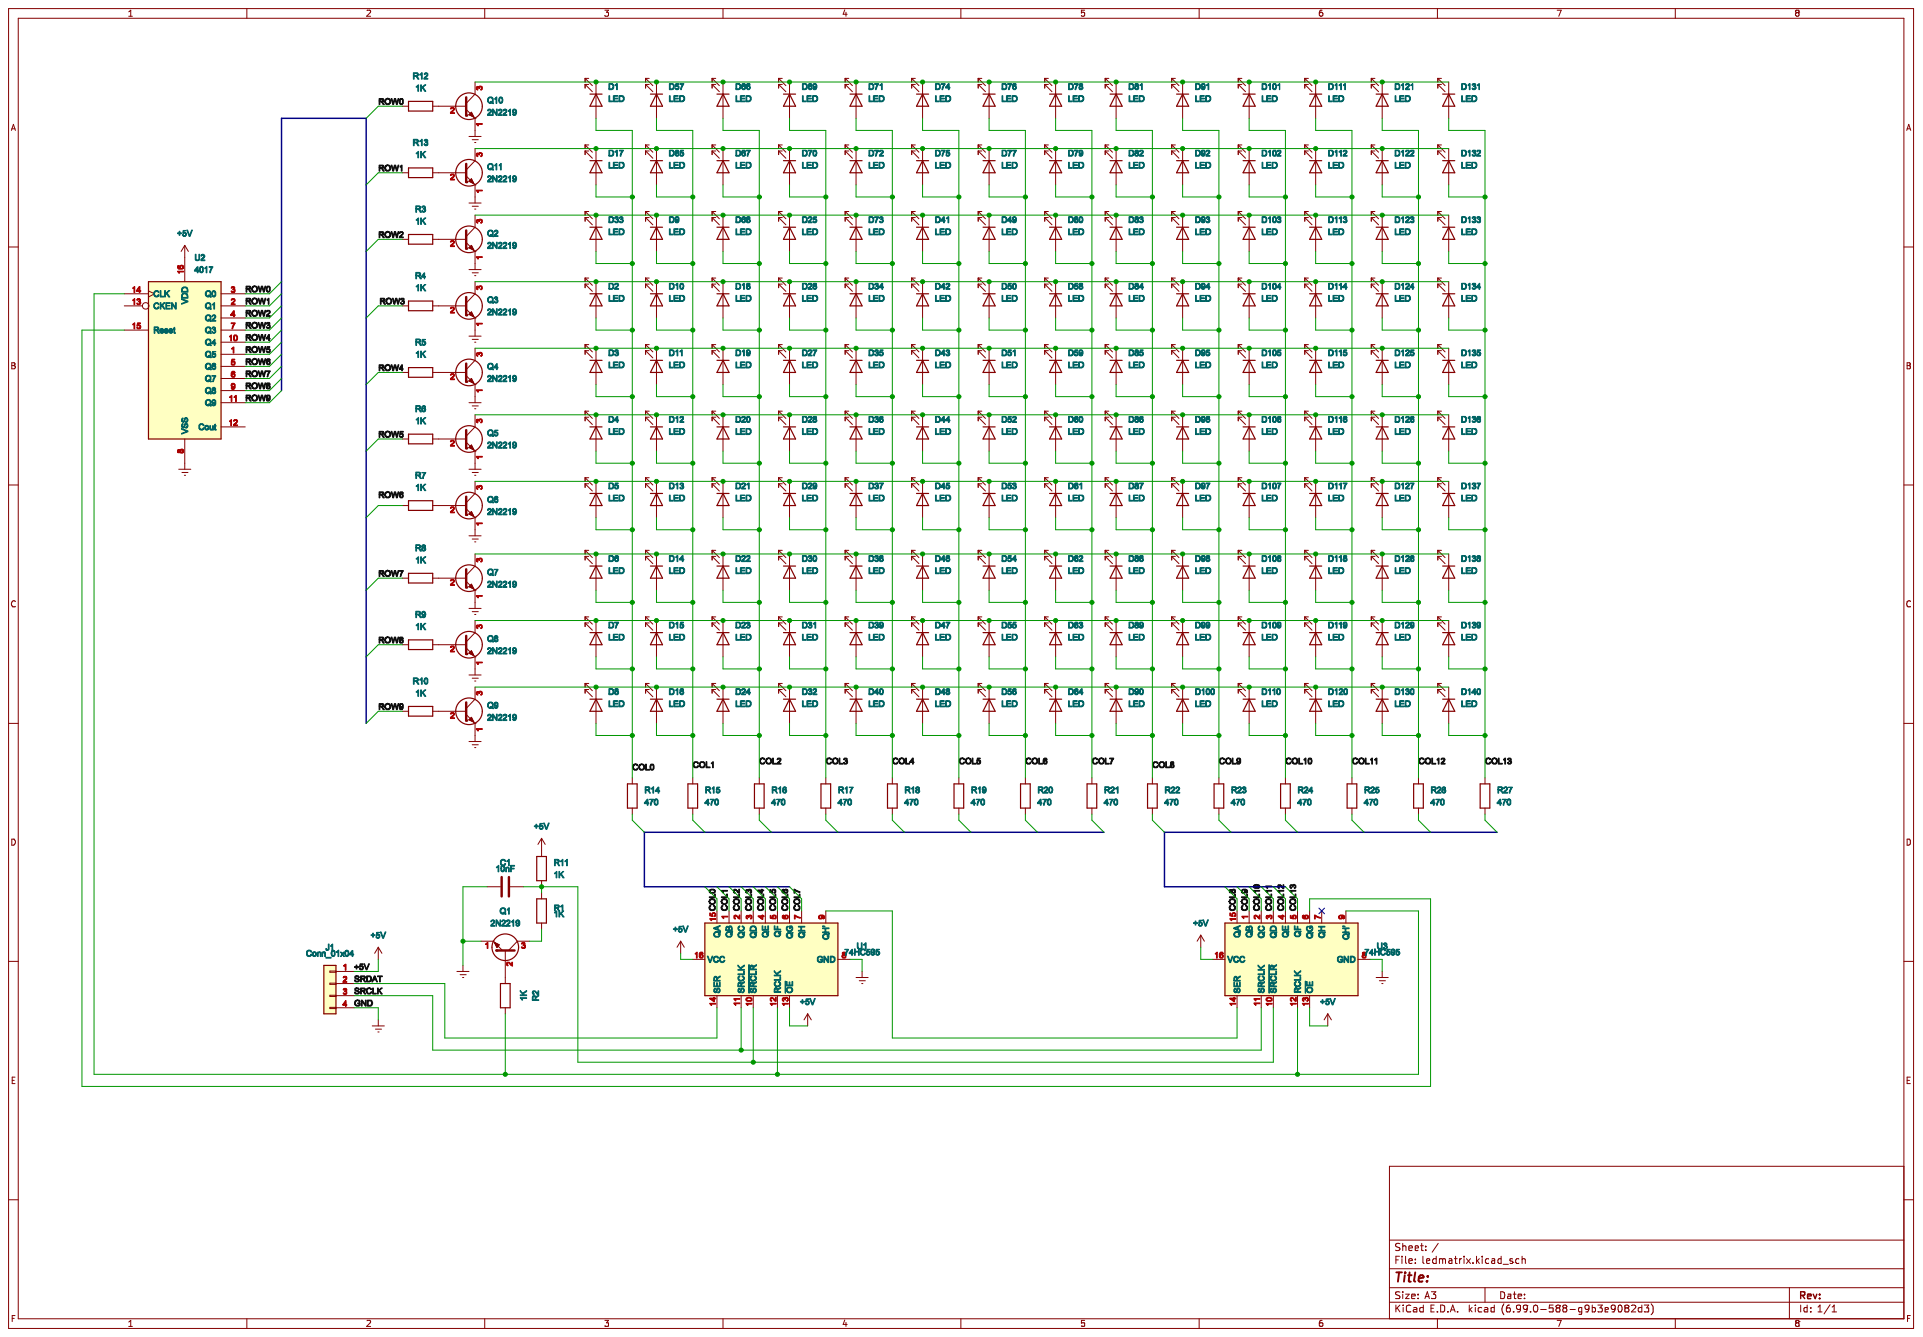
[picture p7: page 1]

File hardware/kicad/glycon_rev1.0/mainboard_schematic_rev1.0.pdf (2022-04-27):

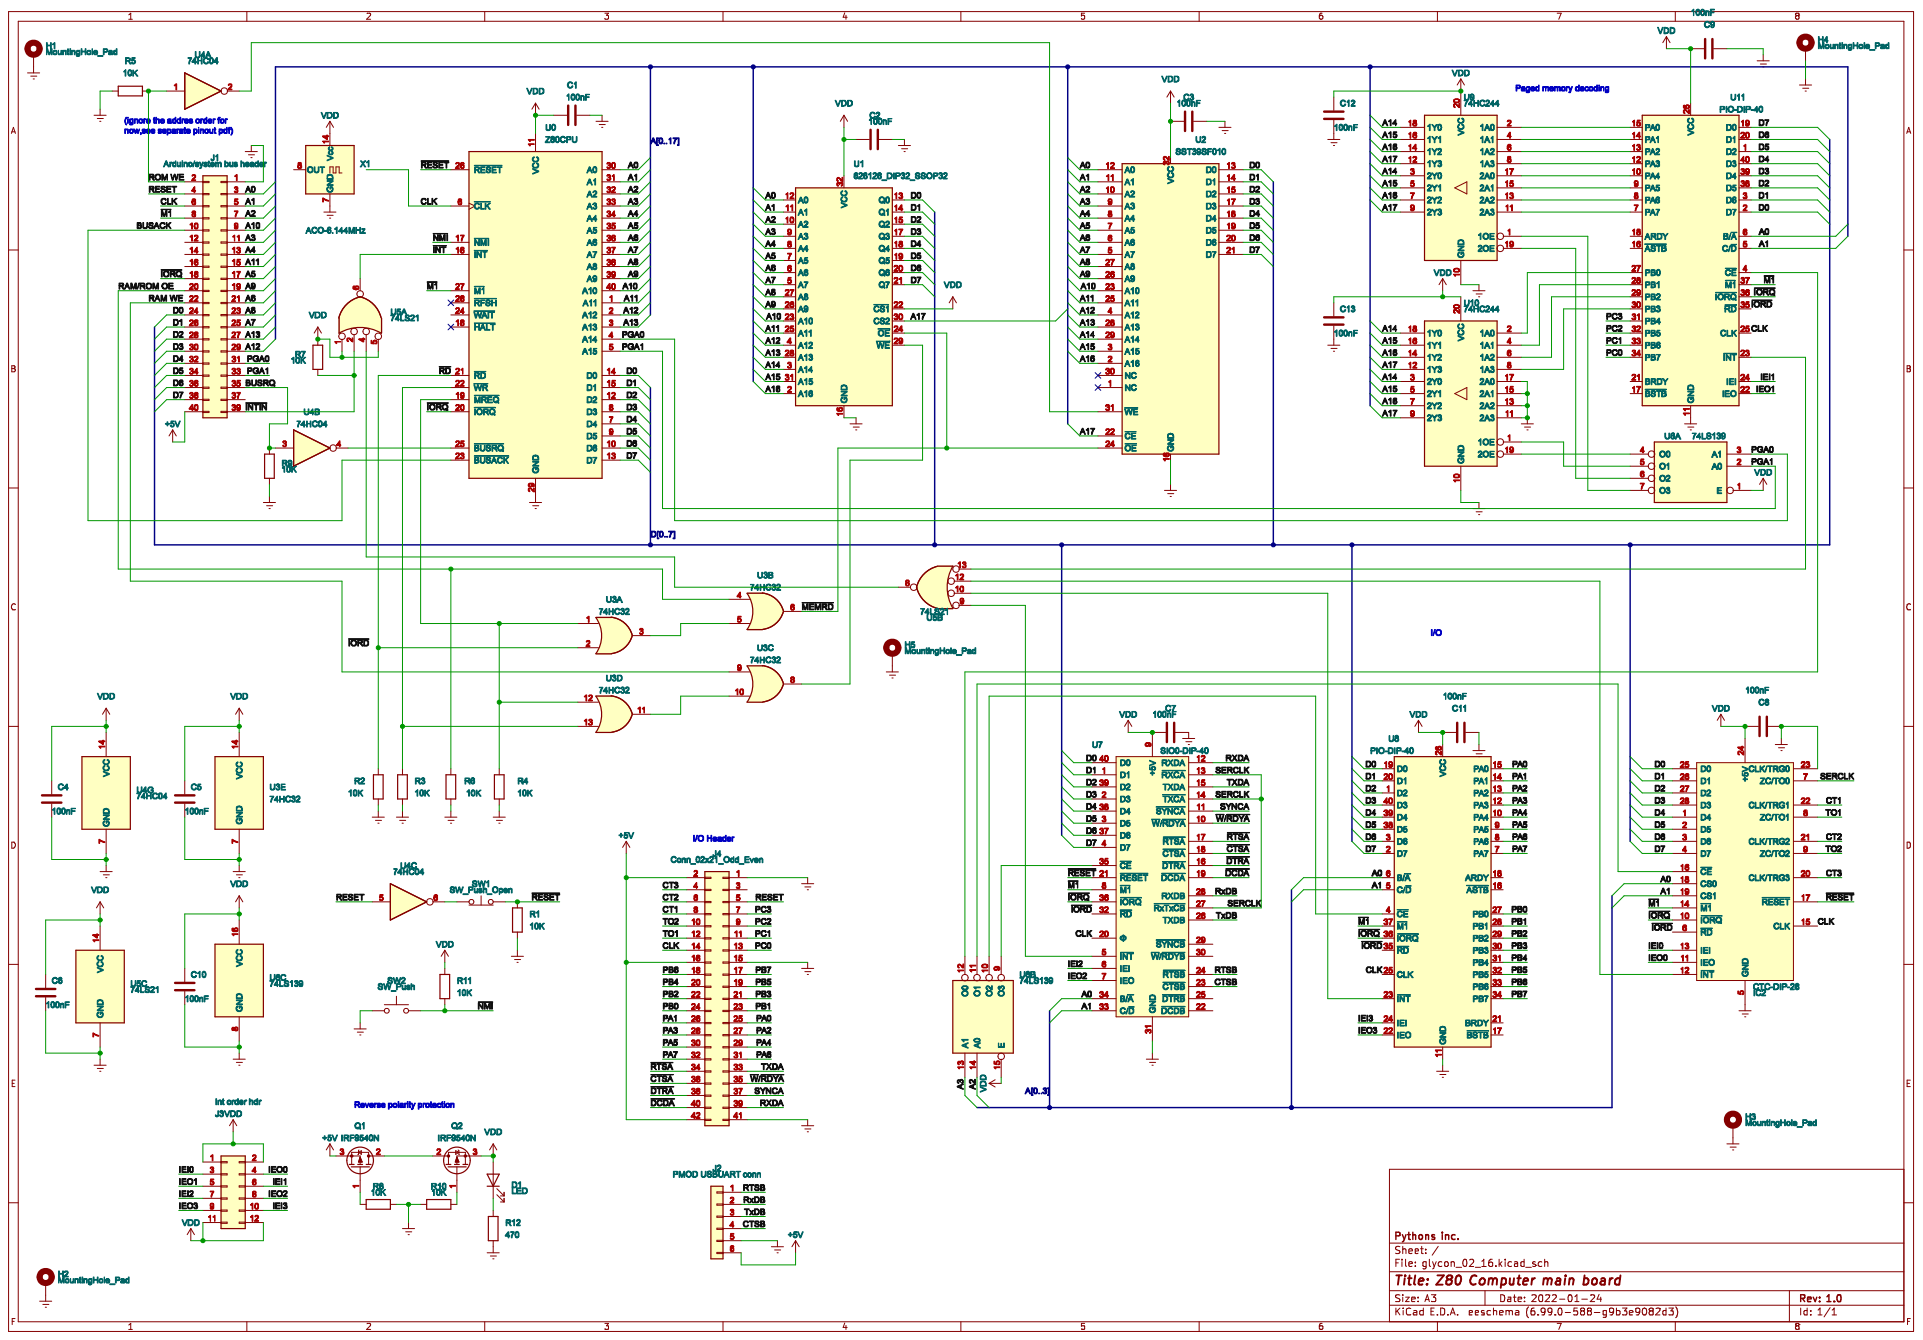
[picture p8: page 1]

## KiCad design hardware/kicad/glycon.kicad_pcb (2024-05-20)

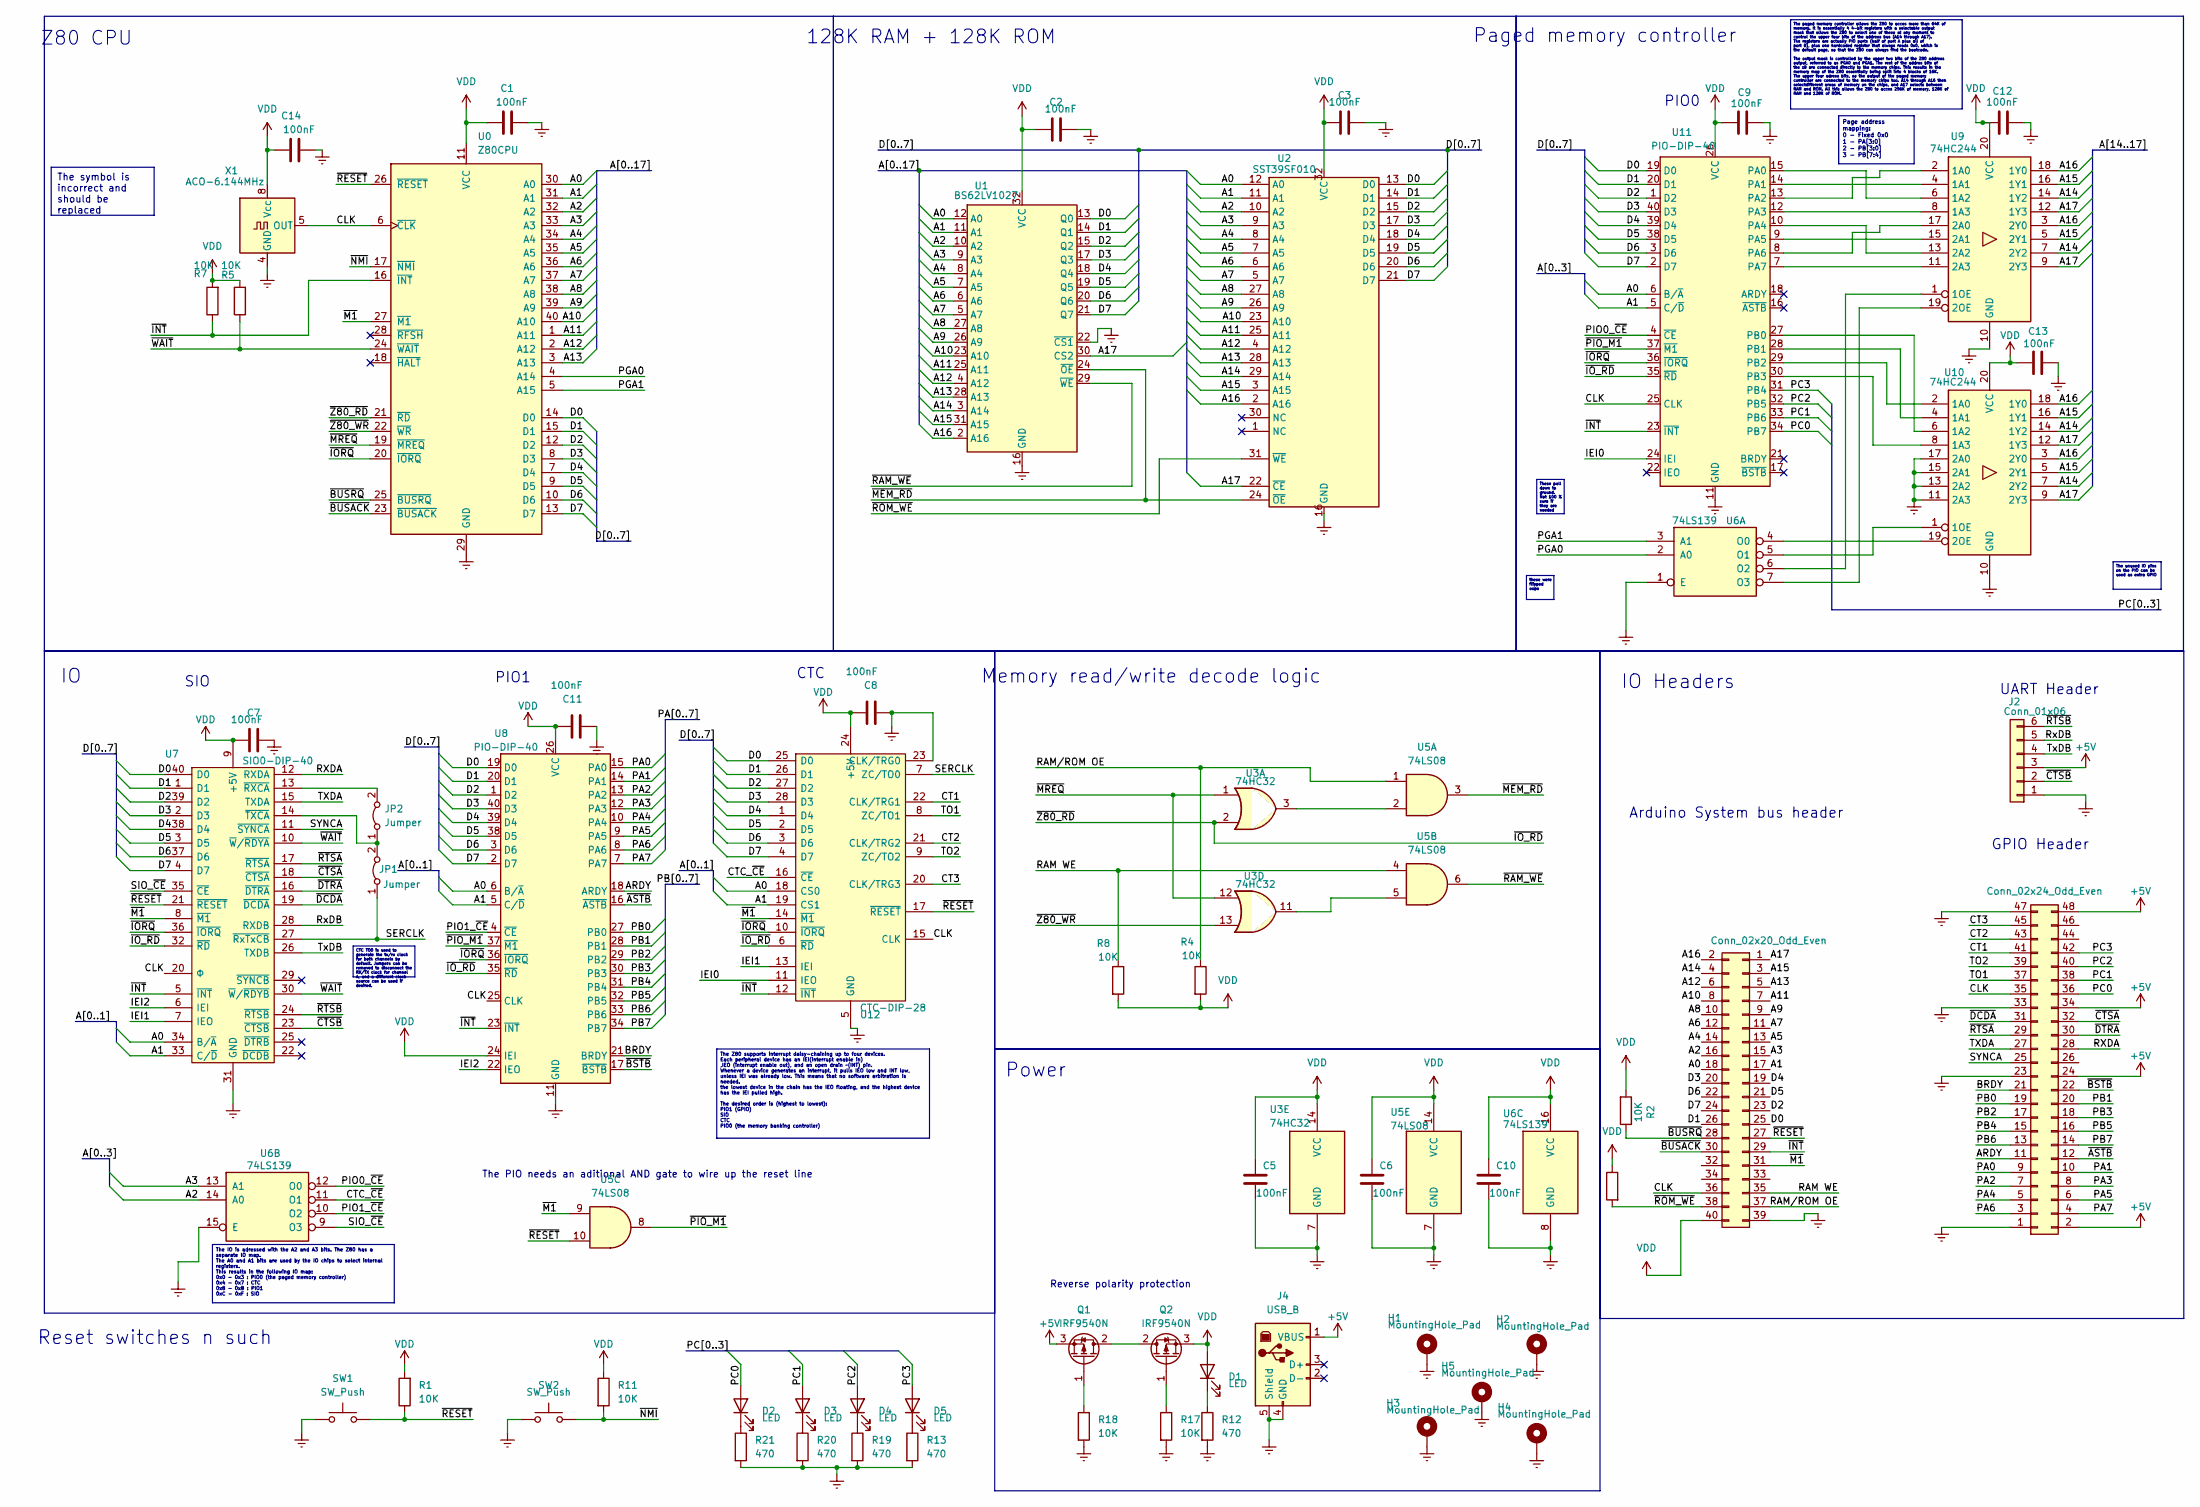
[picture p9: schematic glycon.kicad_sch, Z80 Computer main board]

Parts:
C1, C2, C3, C5, C6, C7, C8, C9, C10, C11, C12, C13, C14: 100nF; C_Disc_D4.7mm_W2.5mm_P5.00mm
D1, D2, D3, D4, D5: LED; LED_D5.0mm
H1, H2, H3, H4, H5: MountingHole_Pad; MountingHole_3.2mm_M3_Pad
J1: Conn_02x20_Odd_Even; PinSocket_2x20_P2.54mm_Vertical
J2: Conn_01x06; PinHeader_1x06_P2.54mm_Vertical
J3: Conn_02x24_Odd_Even; PinSocket_2x24_P2.54mm_Vertical
J4: USB_B; USB_B_TE_5787834_Vertical
JP1, JP2: Jumper; PinHeader_2x01_P2.54mm_Vertical
Q1, Q2: IRF9540N; TO-220-3_Vertical
R1, R2, R3, R4, R5, R7, R8, R11, R17, R18: 10K; R_Axial_DIN0207_L6.3mm_D2.5mm_P10.16mm_Horizontal
R12, R13, R19, R20, R21: 470; R_Axial_DIN0207_L6.3mm_D2.5mm_P10.16mm_Horizontal
SW1, SW2: SW_Push; SW_PUSH_6mm
U0: Z80CPU; DIP-40_W15.24mm_Socket
U1: BS62LV1027; DIP-32_W15.24mm_Socket
U2: SST39SF010; DIP-32_W15.24mm_Socket
U3: 74HC32; DIP-14_W7.62mm_Socket
U5: 74LS08; DIP-14_W7.62mm_Socket
U6: 74LS139; DIP-16_W7.62mm_Socket
U7: SIO0-DIP-40; DIP-40_W15.24mm_Socket; Manufacturer_Part_Number Z84C4206PEG; Mouser Part Number 692-Z84C4206PEG
U8, U11: PIO-DIP-40; DIP-40_W15.24mm_Socket
U9, U10: 74HC244; DIP-20_W7.62mm_Socket
U12: CTC-DIP-28; DIP-28_W15.24mm_Socket; Manufacturer_Part_Number Z84C3010PEG; Mouser Part Number 692-Z84C3010PEG
X1: ACO-6.144MHz; Oscillator_DIP-8

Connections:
+5V: J2.3, J3.2, J3.24, J3.34, J3.48, J4.1 (VBUS), Q1.3 (S)
/A0: J1.18, U0.30 (A0), U1.12 (A0), U2.12 (A0), U7.34 (B/~A), U8.6 (B/~A), U11.6 (B/~A), U12.18 (CS0)
/A1: J1.17, U0.31 (A1), U1.11 (A1), U2.11 (A1), U7.33 (C/~D), U8.5 (C/~D), U11.5 (C/~D), U12.19 (CS1)
/A2: J1.16, U0.32 (A2), U1.10 (A2), U2.10 (A2), U6.14 (A0)
/A3: J1.15, U0.33 (A3), U1.9 (A3), U2.9 (A3), U6.13 (A1)
/A4: J1.14, U0.34 (A4), U1.8 (A4), U2.8 (A4)
/A5: J1.13, U0.35 (A5), U1.7 (A5), U2.7 (A5)
/A6: J1.12, U0.36 (A6), U1.6 (A6), U2.6 (A6)
/A7: J1.11, U0.37 (A7), U1.5 (A7), U2.5 (A7)
/A8: J1.10, U0.38 (A8), U1.27 (A8), U2.27 (A8)
/A9: J1.9, U0.39 (A9), U1.26 (A9), U2.26 (A9)
/A10: J1.8, U0.40 (A10), U1.23 (A10), U2.23 (A10)
/A11: J1.7, U0.1 (A11), U1.25 (A11), U2.25 (A11)
/A12: J1.6, U0.2 (A12), U1.4 (A12), U2.4 (A12)
/A13: J1.5, U0.3 (A13), U1.28 (A13), U2.28 (A13)
/A14: J1.4, U1.3 (A14), U2.29 (A14), U9.7 (2Y2), U9.14 (1Y2), U10.7 (2Y2), U10.14 (1Y2)
/A15: J1.3, U1.31 (A15), U2.3 (A15), U9.5 (2Y1), U9.16 (1Y1), U10.5 (2Y1), U10.16 (1Y1)
/A16: J1.2, U1.2 (A16), U2.2 (A16), U9.3 (2Y0), U9.18 (1Y0), U10.3 (2Y0), U10.18 (1Y0)
/A17: J1.1, U1.30 (CS2), U2.22 (~CE), U9.9 (2Y3), U9.12 (1Y3), U10.9 (2Y3), U10.12 (1Y3)
/ARDY: J3.11, U8.18 (ARDY)
/BRDY: J3.21, U8.21 (BRDY)
/CLK: J1.36, J3.35, U0.6 (~CLK), U7.20 (Φ), U8.25 (CLK), U11.25 (CLK), U12.15 (CLK), X1.5 (OUT)
/CT1: J3.41, U12.22 (CLK/TRG1)
/CT2: J3.43, U12.21 (CLK/TRG2)
/CT3: J3.45, U12.20 (CLK/TRG3)
/CTC_~CE: U6.11 (O1), U12.16 (~CE)
/D0: J1.25, U0.14 (D0), U1.13 (Q0), U2.13 (D0), U7.40 (D0), U8.19 (D0), U11.19 (D0), U12.25 (D0)
/D1: J1.26, U0.15 (D1), U1.14 (Q1), U2.14 (D1), U7.1 (D1), U8.20 (D1), U11.20 (D1), U12.26 (D1)
/D2: J1.23, U0.12 (D2), U1.15 (Q2), U2.15 (D2), U7.39 (D2), U8.1 (D2), U11.1 (D2), U12.27 (D2)
/D3: J1.20, U0.8 (D3), U1.17 (Q3), U2.17 (D3), U7.2 (D3), U8.40 (D3), U11.40 (D3), U12.28 (D3)
/D4: J1.19, U0.7 (D4), U1.18 (Q4), U2.18 (D4), U7.38 (D4), U8.39 (D4), U11.39 (D4), U12.1 (D4)
/D5: J1.21, U0.9 (D5), U1.19 (Q5), U2.19 (D5), U7.3 (D5), U8.38 (D5), U11.38 (D5), U12.2 (D5)
/D6: J1.22, U0.10 (D6), U1.20 (Q6), U2.20 (D6), U7.37 (D6), U8.3 (D6), U11.3 (D6), U12.3 (D6)
/D7: J1.24, U0.13 (D7), U1.21 (Q7), U2.21 (D7), U7.4 (D7), U8.2 (D7), U11.2 (D7), U12.4 (D7)
/IEI0: U11.24 (IEI), U12.11 (IEO)
/IEI1: U7.7 (IEO), U12.13 (IEI)
/IEI2: U7.6 (IEI), U8.22 (IEO)
/PA0: J3.9, U8.15 (PA0)
/PA1: J3.10, U8.14 (PA1)
/PA2: J3.7, U8.13 (PA2)
/PA3: J3.8, U8.12 (PA3)
/PA4: J3.5, U8.10 (PA4)
/PA5: J3.6, U8.9 (PA5)
/PA6: J3.3, U8.8 (PA6)
/PA7: J3.4, U8.7 (PA7)
/PB0: J3.19, U8.27 (PB0)
/PB1: J3.20, U8.28 (PB1)
/PB2: J3.17, U8.29 (PB2)
/PB3: J3.18, U8.30 (PB3)
/PB4: J3.15, U8.31 (PB4)
/PB5: J3.16, U8.32 (PB5)
/PB6: J3.13, U8.33 (PB6)
/PB7: J3.14, U8.34 (PB7)
/PC0: D2.2 (A), J3.36, U11.34 (PB7)
/PC1: D3.2 (A), J3.38, U11.33 (PB6)
/PC2: D4.2 (A), J3.40, U11.32 (PB5)
/PC3: D5.2 (A), J3.42, U11.31 (PB4)
/PGA0: U0.4 (A14), U6.2 (A0)
/PGA1: U0.5 (A15), U6.3 (A1)
/PIO0_~CE: U6.12 (O0), U11.4 (~CE)
/PIO1_~CE: U6.10 (O2), U8.4 (~CE)
/RAM WE: J1.35, R8.1, U5.4
/RAM/ROM OE: J1.37, R4.1, U5.1
/RXDA: J3.28, U7.12 (RXDA)
/RxDB: J2.5, U7.28 (RXDB)
/SERCLK: JP1.1 (A), U7.27 (~RxTxCB), U12.7 (ZC/TO0)
/SIO_~CE: U6.9 (O3), U7.35 (~CE)
/SYNCA: J3.25, U7.11 (~SYNCA)
/TO1: J3.37, U12.8 (ZC/TO1)
/TO2: J3.39, U12.9 (ZC/TO2)
/TXDA: J3.27, U7.15 (TXDA)
/TxDB: J2.4, U7.26 (TXDB)
/~ASTB: J3.12, U8.16 (~ASTB)
/~BSTB: J3.22, U8.17 (~BSTB)
/~BUSACK: J1.30, U0.23 (~BUSACK)
/~BUSRQ: J1.28, R2.1, U0.25 (~BUSRQ)
/~CTSA: J3.32, U7.18 (~CTSA)
/~CTSB: J2.2, U7.23 (~CTSB)
/~DCDA: J3.31, U7.19 (~DCDA)
/~DTRA: J3.30, U7.16 (~DTRA)
/~INT: J1.29, R7.1, U0.16 (~INT), U7.5 (~INT), U8.23 (~INT), U11.23 (~INT), U12.12 (~INT)
/~IORQ: U0.20 (~IORQ), U7.36 (~IORQ), U8.36 (~IORQ), U11.36 (~IORQ), U12.10 (~IORQ)
/~IO_RD: U0.21 (~RD), U3.2, U7.32 (~RD), U8.35 (~RD), U11.35 (~RD), U12.6 (~RD)
/~M1: J1.31, U0.27 (~M1), U5.9, U7.8 (~M1), U12.14 (~M1)
/~MEM_RD: U1.24 (~OE), U2.24 (~OE), U5.3
/~MREQ: U0.19 (~MREQ), U3.1, U3.12
/~NMI: R11.2, SW2.2, U0.17 (~NMI)
/~PIO_M1: U5.8, U8.37 (~M1), U11.37 (~M1)
/~RAM_WE: U1.29 (~WE), U5.6
/~RESET: J1.27, R1.1, SW1.2, U0.26 (~RESET), U5.10, U7.21 (~RESET), U12.17 (~RESET)
/~ROM_WE: J1.38, R3.2, U2.31 (~WE)
/~RTSA: J3.29, U7.17 (~RTSA)
/~RTSB: J2.6, U7.24 (~RTSB)
/~WAIT: R5.1, U0.24 (~WAIT), U7.10 (~W/~RDYA), U7.30 (~W/~RDYB)
/~Z80_WR: U0.22 (~WR), U3.13
Earth: C1.2, C2.2, C3.1, C5.2, C6.2, C7.2, C8.2, C9.1, C10.2, C11.2, C12.2, C13.2, C14.2, H1.1, H2.1, H3.1, H4.1, H5.1, J1.39, J2.1, J3.1, J3.23, J3.33, J3.47, J4.4 (GND), J4.5 (Shield), R12.2, R13.2, R17.2, R18.2, R19.2, R20.2, R21.2, SW1.1, SW2.1, U0.29 (GND), U1.16 (GND), U1.22 (~CS1), U2.16 (GND), U3.7 (GND), U5.7 (GND), U6.1 (E), U6.8 (GND), U6.15 (E), U7.31 (GND), U8.11 (GND), U9.10 (GND), U10.10 (GND), U10.11 (2A3), U10.13 (2A2), U10.15 (2A1), U10.17 (2A0), U11.11 (GND), U12.5 (GND), U12.23 (CLK/TRG0), X1.4 (GND)
unnamed: D1.1 (K), R12.1
unnamed: D2.1 (K), R21.1
unnamed: D3.1 (K), R20.1
unnamed: D4.1 (K), R19.1
unnamed: D5.1 (K), R13.1
unnamed: JP1.2 (B), JP2.1 (A), U7.14 (~TXCA)
unnamed: JP2.2 (B), U7.13 (~RXCA)
unnamed: Q1.2 (D), Q2.2 (D)
unnamed: Q1.1 (G), R18.1
unnamed: Q2.1 (G), R17.1
unnamed: U3.3, U5.2
unnamed: U3.11, U5.5
unnamed: U6.6 (O2), U9.1 (1OE)
unnamed: U6.7 (O3), U9.19 (2OE)
unnamed: U10.2 (1A0), U11.29 (PB2)
unnamed: U10.4 (1A1), U11.28 (PB1)
unnamed: U10.6 (1A2), U11.27 (PB0)
unnamed: U10.8 (1A3), U11.30 (PB3)
unnamed: U6.5 (O1), U10.1 (1OE)
unnamed: U6.4 (O0), U10.19 (2OE)
unnamed: U9.6 (1A2), U11.15 (PA0)
unnamed: U9.4 (1A1), U11.14 (PA1)
unnamed: U9.2 (1A0), U11.13 (PA2)
unnamed: U9.8 (1A3), U11.12 (PA3)
unnamed: U9.13 (2A2), U11.10 (PA4)
unnamed: U9.15 (2A1), U11.9 (PA5)
unnamed: U9.17 (2A0), U11.8 (PA6)
unnamed: U9.11 (2A3), U11.7 (PA7)
VDD: C1.1, C2.1, C3.2, C5.1, C6.1, C7.1, C8.1, C9.2, C10.1, C11.1, C12.1, C13.1, C14.1, D1.2 (A), J1.40, Q2.3 (S), R1.2, R2.2, R3.1, R4.2, R5.2, R7.2, R8.2, R11.1, U0.11 (VCC), U1.32 (VCC), U2.32 (VCC), U3.14 (VCC), U5.14 (VCC), U6.16 (VCC), U7.9 (+5V), U8.24 (IEI), U8.26 (VCC), U9.20 (VCC), U10.20 (VCC), U11.26 (VCC), U12.24 (+5V), X1.8 (Vcc)

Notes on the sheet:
CTC TO0 is used to generate the tx/rx clock for both channels by default. Jumpers can be removed to disconnect the RX/TX clock for channel A, and a different clock source can be used if desired.
The unused IO pins on the PIO can be used as extra GPIO
The IO is adressed with the A2 and A3 bits. The Z80 has a separate IO map. The A0 and A1 bits are used by the IO chips to select internal registers. This results in the following IO map: 0x0 - 0x3 : PIO0 (the paged memory controller) 0x4 - 0x7 : CTC 0x8 - 0xB : PIO1 0xC - 0xF : SIO
these were flipped oops
These pull down to ground. Not 100 % sure if they are needed
The Z80 supports interrupt daisy-chaining up to four devices. Each peripheral device has an IEI(interrupt enable in) ,IEO (interrupt enable out), and an open drain ~(INT) pin. Whenever a device generates an interrupt, it pulls IEO low and INT low, unless IEI was already low. This means that no soft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
The paged memory controller allows the Z80 to acces more than 64K of memory. It is essentially 4 4-bit registers with a selectable output mask that allows the Z80 to select one of these at any moment to control the upper four bits of the address bus (A14 through A17). The registers are actually PIO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
Page address mapping: 0 - Fixed 0x0 1 - PA[3:0] 2 - PB[3:0] 3 - PB[7:4]
The symbol is incorrect and should be replaced
Reset switches n such
UART Header
CTC
Power
PIO0
Z80 CPU
SIO
IO Headers
128K RAM + 128K ROM
The PIO needs an aditional AND gate to wire up the reset line
Paged memory controller
Reverse polarity protection
GPIO Header
Memory read/write decode logic
Arduino System bus header
PIO1

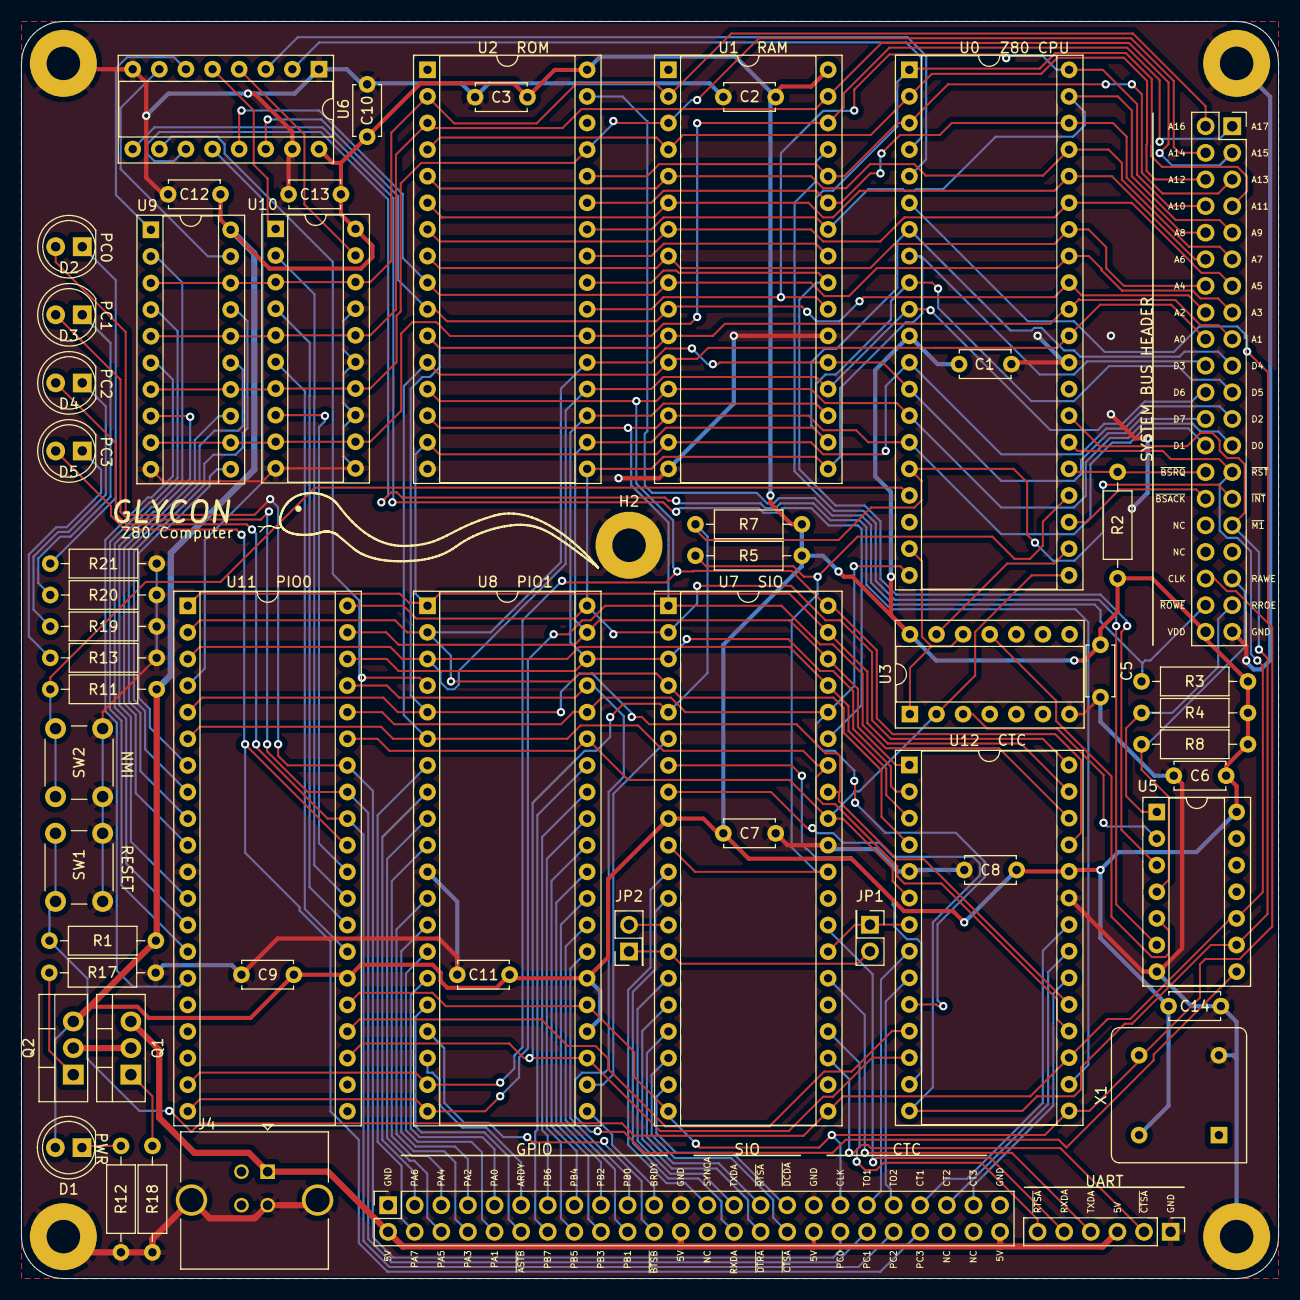
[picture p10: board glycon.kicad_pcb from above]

Board: 2 copper layers, 120.0 x 120.0 mm, 61 parts (0 on the bottom side), 125 nets.

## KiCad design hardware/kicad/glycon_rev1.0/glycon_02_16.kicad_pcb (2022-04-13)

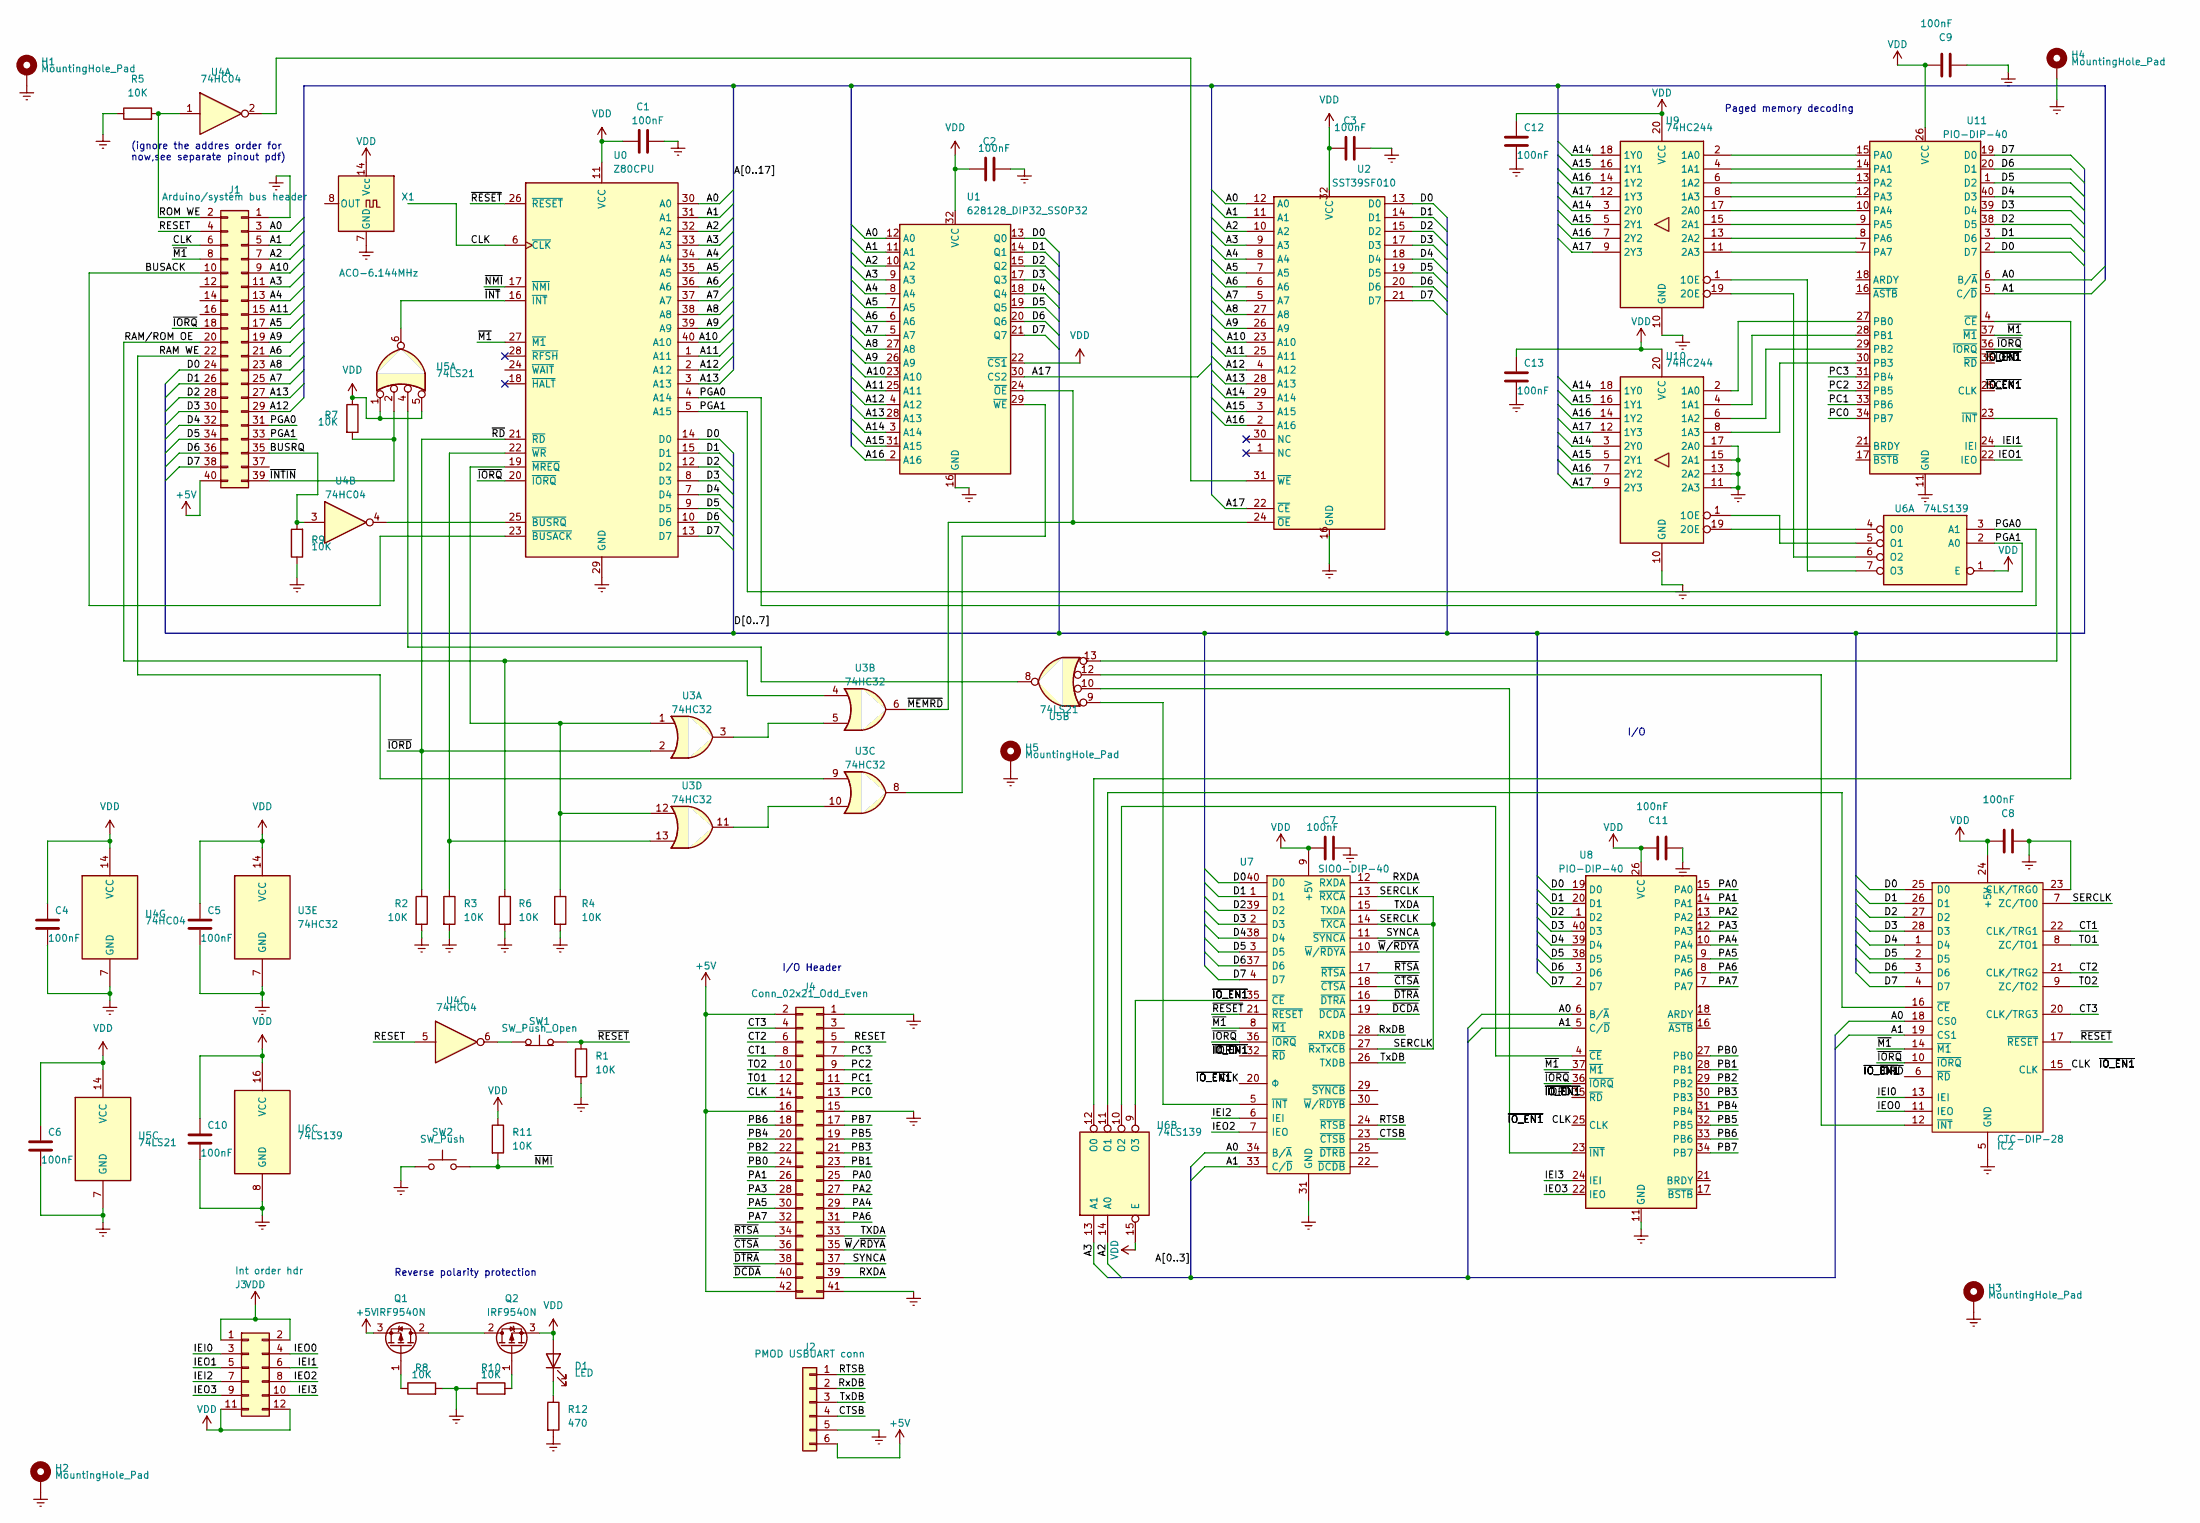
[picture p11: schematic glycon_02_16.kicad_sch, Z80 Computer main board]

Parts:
C1, C2, C3, C4, C5, C6, C7, C8, C9, C10, C11, C12, C13: 100nF; C_Disc_D4.7mm_W2.5mm_P5.00mm
D1: LED; LED_D5.0mm
H1, H2, H3, H4, H5: MountingHole_Pad; MountingHole_3.2mm_M3_Pad
IC2: CTC-DIP-28; DIP-28_W15.24mm_Socket; Manufacturer_Part_Number Z84C3010PEG; Mouser Part Number 692-Z84C3010PEG
J1: Arduino/system bus header; PinSocket_2x20_P2.54mm_Vertical
J2: PMOD USBUART conn; PinHeader_1x06_P2.54mm_Vertical
J3: Int order hdr; PinHeader_2x06_P2.54mm_Vertical
J4: Conn_02x21_Odd_Even; PinSocket_2x21_P2.54mm_Vertical
Q1, Q2: IRF9540N; TO-220-3_Vertical
R1, R2, R3, R4, R5, R6, R7, R8, R9, R10, R11: 10K; R_Axial_DIN0204_L3.6mm_D1.6mm_P5.08mm_Horizontal
R12: 470; R_Axial_DIN0204_L3.6mm_D1.6mm_P5.08mm_Horizontal
SW1: SW_Push_Open; SW_PUSH_6mm
SW2: SW_Push; SW_PUSH_6mm
U0: Z80CPU; DIP-40_W15.24mm_Socket
U1: 628128_DIP32_SSOP32; DIP-32_W15.24mm_Socket
U2: SST39SF010; DIP-32_W15.24mm_Socket
U3: 74HC32; DIP-14_W7.62mm_Socket
U4: 74HC04; DIP-14_W7.62mm_Socket
U5: 74LS21; DIP-14_W7.62mm_Socket
U6: 74LS139; DIP-16_W7.62mm_Socket
U7: SIO0-DIP-40; DIP-40_W15.24mm_Socket; Manufacturer_Part_Number Z84C4206PEG; Mouser Part Number 692-Z84C4206PEG
U8, U11: PIO-DIP-40; DIP-40_W15.24mm_Socket
U9, U10: 74HC244; DIP-20_W7.62mm_Socket
X1: ACO-6.144MHz; Oscillator_DIP-14

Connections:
+5V: J1.40, J2.6, J4.2, J4.16, J4.42, Q1.3 (S)
/A0: IC2.18 (CS0), J1.3, U0.30 (A0), U1.12 (A0), U2.12 (A0), U7.34 (B/~A), U8.6 (B/~A), U11.6 (B/~A)
/A1: IC2.19 (CS1), J1.5, U0.31 (A1), U1.11 (A1), U2.11 (A1), U7.33 (C/~D), U8.5 (C/~D), U11.5 (C/~D)
/A2: J1.7, U0.32 (A2), U1.10 (A2), U2.10 (A2), U6.14 (A0)
/A3: J1.11, U0.33 (A3), U1.9 (A3), U2.9 (A3), U6.13 (A1)
/A4: J1.13, U0.34 (A4), U1.8 (A4), U2.8 (A4)
/A5: J1.17, U0.35 (A5), U1.7 (A5), U2.7 (A5)
/A6: J1.21, U0.36 (A6), U1.6 (A6), U2.6 (A6)
/A7: J1.25, U0.37 (A7), U1.5 (A7), U2.5 (A7)
/A8: J1.23, U0.38 (A8), U1.27 (A8), U2.27 (A8)
/A9: J1.19, U0.39 (A9), U1.26 (A9), U2.26 (A9)
/A10: J1.9, U0.40 (A10), U1.23 (A10), U2.23 (A10)
/A11: J1.15, U0.1 (A11), U1.25 (A11), U2.25 (A11)
/A12: J1.29, U0.2 (A12), U1.4 (A12), U2.4 (A12)
/A13: J1.27, U0.3 (A13), U1.28 (A13), U2.28 (A13)
/A14: U1.3 (A14), U2.29 (A14), U9.3 (2Y0), U9.18 (1Y0), U10.3 (2Y0), U10.18 (1Y0)
/A15: U1.31 (A15), U2.3 (A15), U9.5 (2Y1), U9.16 (1Y1), U10.5 (2Y1), U10.16 (1Y1)
/A16: U1.2 (A16), U2.2 (A16), U9.7 (2Y2), U9.14 (1Y2), U10.7 (2Y2), U10.14 (1Y2)
/A17: U1.30 (CS2), U2.22 (~CE), U9.9 (2Y3), U9.12 (1Y3), U10.9 (2Y3), U10.12 (1Y3)
/BUSACK: J1.10, U0.23 (~BUSACK)
/BUSRQ: J1.35, R9.2, U4.3
/CLK: IC2.15 (CLK), J1.6, J4.14, U0.6 (~CLK), U7.20 (Φ), U8.25 (CLK), U11.25 (CLK), X1.1 (NC), X1.8 (OUT)
/CT1: IC2.22 (CLK/TRG1), J4.8
/CT2: IC2.21 (CLK/TRG2), J4.6
/CT3: IC2.20 (CLK/TRG3), J4.4
/CTSB: J2.4, U7.23 (~CTSB)
/D0: IC2.25 (D0), J1.24, U0.14 (D0), U1.13 (Q0), U2.13 (D0), U7.40 (D0), U8.19 (D0), U11.2 (D7)
/D1: IC2.26 (D1), J1.26, U0.15 (D1), U1.14 (Q1), U2.14 (D1), U7.1 (D1), U8.20 (D1), U11.3 (D6)
/D2: IC2.27 (D2), J1.28, U0.12 (D2), U1.15 (Q2), U2.15 (D2), U7.39 (D2), U8.1 (D2), U11.38 (D5)
/D3: IC2.28 (D3), J1.30, U0.8 (D3), U1.17 (Q3), U2.17 (D3), U7.2 (D3), U8.40 (D3), U11.39 (D4)
/D4: IC2.1 (D4), J1.32, U0.7 (D4), U1.18 (Q4), U2.18 (D4), U7.38 (D4), U8.39 (D4), U11.40 (D3)
/D5: IC2.2 (D5), J1.34, U0.9 (D5), U1.19 (Q5), U2.19 (D5), U7.3 (D5), U8.38 (D5), U11.1 (D2)
/D6: IC2.3 (D6), J1.36, U0.10 (D6), U1.20 (Q6), U2.20 (D6), U7.37 (D6), U8.3 (D6), U11.20 (D1)
/D7: IC2.4 (D7), J1.38, U0.13 (D7), U1.21 (Q7), U2.21 (D7), U7.4 (D7), U8.2 (D7), U11.19 (D0)
/IEI0: IC2.13 (IEI), J3.3
/IEI1: J3.6, U11.24 (IEI)
/IEI2: J3.7, U7.6 (IEI)
/IEI3: J3.10, U8.24 (IEI)
/IEO0: IC2.11 (IEO), J3.4
/IEO1: J3.5, U11.22 (IEO)
/IEO2: J3.8, U7.7 (IEO)
/IEO3: J3.9, U8.22 (IEO)
/PA0: J4.25, U8.15 (PA0)
/PA1: J4.26, U8.14 (PA1)
/PA2: J4.27, U8.13 (PA2)
/PA3: J4.28, U8.12 (PA3)
/PA4: J4.29, U8.10 (PA4)
/PA5: J4.30, U8.9 (PA5)
/PA6: J4.31, U8.8 (PA6)
/PA7: J4.32, U8.7 (PA7)
/PB0: J4.24, U8.27 (PB0)
/PB1: J4.23, U8.28 (PB1)
/PB2: J4.22, U8.29 (PB2)
/PB3: J4.21, U8.30 (PB3)
/PB4: J4.20, U8.31 (PB4)
/PB5: J4.19, U8.32 (PB5)
/PB6: J4.18, U8.33 (PB6)
/PB7: J4.17, U8.34 (PB7)
/PC0: J4.13, U11.34 (PB7)
/PC1: J4.11, U11.33 (PB6)
/PC2: J4.9, U11.32 (PB5)
/PC3: J4.7, U11.31 (PB4)
/PGA0: J1.31, U0.4 (A14), U6.3 (A1)
/PGA1: J1.33, U0.5 (A15), U6.2 (A0)
/RAM WE: J1.22, U3.9
/RAM/ROM OE: J1.20, R6.1, U3.4
/RESET: J1.4, J4.5, U4.5
/ROM WE: J1.2, R5.2, U4.1
/RTSB: J2.1, U7.24 (~RTSB)
/RXDA: J4.39, U7.12 (RXDA)
/RxDB: J2.2, U7.28 (RXDB)
/SERCLK: IC2.7 (ZC/TO0), U7.13 (~RXCA), U7.14 (~TXCA), U7.27 (~RxTxCB)
/SYNCA: J4.37, U7.11 (~SYNCA)
/TO1: IC2.8 (ZC/TO1), J4.12
/TO2: IC2.9 (ZC/TO2), J4.10
/TXDA: J4.33, U7.15 (TXDA)
/TxDB: J2.3, U7.26 (TXDB)
/~CTSA: J4.36, U7.18 (~CTSA)
/~DCDA: J4.40, U7.19 (~DCDA)
/~DTRA: J4.38, U7.16 (~DTRA)
/~INTIN: J1.39, R7.2, U5.2
/~INT: U0.16 (~INT), U5.6
/~IORQ: IC2.10 (~IORQ), J1.18, U0.20 (~IORQ), U7.36 (~IORQ), U8.36 (~IORQ), U11.36 (~IORQ)
/~IO_EN1: U6.9 (O3), U7.35 (~CE)
/~M1: IC2.14 (~M1), J1.8, U0.27 (~M1), U7.8 (~M1), U8.37 (~M1), U11.37 (~M1)
/~MEMRD: U1.24 (~OE), U2.24 (~OE), U3.6
/~NMI: R11.2, SW2.2, U0.17 (~NMI)
/~RESET: IC2.17 (~RESET), R1.1, SW1.2 (B), U0.26 (~RESET), U7.21 (~RESET)
/~RTSA: J4.34, U7.17 (~RTSA)
/~W/~RDYA: J4.35, U7.10 (~W/~RDYA)
Earth: C1.2, C2.2, C3.1, C4.2, C5.2, C6.2, C7.2, C8.2, C9.2, C10.2, C11.2, C12.2, C13.2, H1.1, H2.1, H3.1, H4.1, H5.1, IC2.5 (GND), IC2.23 (CLK/TRG0), J1.1, J2.5, J4.1, J4.15, J4.41, R1.2, R2.2, R3.2, R4.2, R5.1, R6.2, R8.2, R9.1, R10.1, R12.2, SW2.1, U0.29 (GND), U1.16 (GND), U2.16 (GND), U3.7 (GND), U4.7 (GND), U5.7 (GND), U6.8 (GND), U7.31 (GND), U8.11 (GND), U9.10 (GND), U10.10 (GND), U10.11 (2A3), U10.13 (2A2), U10.15 (2A1), U10.17 (2A0), U11.11 (GND), X1.7 (GND)
unnamed: D1.1 (K), R12.1
unnamed: IC2.16 (~CE), U6.11 (O1)
unnamed: IC2.12 (~INT), U5.12
unnamed: Q1.2 (D), Q2.2 (D)
unnamed: Q1.1 (G), R8.1
unnamed: Q2.1 (G), R10.2
unnamed: SW1.1 (A), U4.6
unnamed: U0.25 (~BUSRQ), U4.4
unnamed: R4.1, U0.19 (~MREQ), U3.1, U3.12
unnamed: R3.1, U0.22 (~WR), U3.13
unnamed: U1.29 (~WE), U3.8
unnamed: U2.31 (~WE), U4.2
unnamed: U3.3, U3.5
unnamed: U3.10, U3.11
unnamed: U5.4, U5.8
unnamed: U6.6 (O2), U9.19 (2OE)
unnamed: U6.7 (O3), U9.1 (1OE)
unnamed: U6.10 (O2), U8.4 (~CE)
unnamed: U5.9, U7.5 (~INT)
unnamed: U5.10, U8.23 (~INT)
unnamed: U10.2 (1A0), U11.27 (PB0)
unnamed: U10.4 (1A1), U11.28 (PB1)
unnamed: U10.6 (1A2), U11.29 (PB2)
unnamed: U10.8 (1A3), U11.30 (PB3)
unnamed: U6.5 (O1), U10.1 (1OE)
unnamed: U6.4 (O0), U10.19 (2OE)
unnamed: U9.2 (1A0), U11.15 (PA0)
unnamed: U9.4 (1A1), U11.14 (PA1)
unnamed: U9.6 (1A2), U11.13 (PA2)
unnamed: U9.8 (1A3), U11.12 (PA3)
unnamed: U9.17 (2A0), U11.10 (PA4)
unnamed: U9.15 (2A1), U11.9 (PA5)
unnamed: U9.13 (2A2), U11.8 (PA6)
unnamed: U9.11 (2A3), U11.7 (PA7)
unnamed: U6.12 (O0), U11.4 (~CE)
unnamed: U5.13, U11.23 (~INT)
VDD: C1.1, C2.1, C3.2, C4.1, C5.1, C6.1, C7.1, C8.1, C9.1, C10.1, C11.1, C12.1, C13.1, D1.2 (A), IC2.24 (+5V), J3.1, J3.2, J3.11, J3.12, Q2.3 (S), R7.1, R11.1, U0.11 (VCC), U1.22 (~CS1), U1.32 (VCC), U2.32 (VCC), U3.14 (VCC), U4.14 (VCC), U5.1, U5.5, U5.14 (VCC), U6.1 (E), U6.15 (E), U6.16 (VCC), U7.9 (+5V), U8.26 (VCC), U9.20 (VCC), U10.20 (VCC), U11.26 (VCC), X1.14 (Vcc)

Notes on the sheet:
I/O
Paged memory decoding
Reverse polarity protection
I/O Header
(ignore the addres order for now,see separate pinout pdf)

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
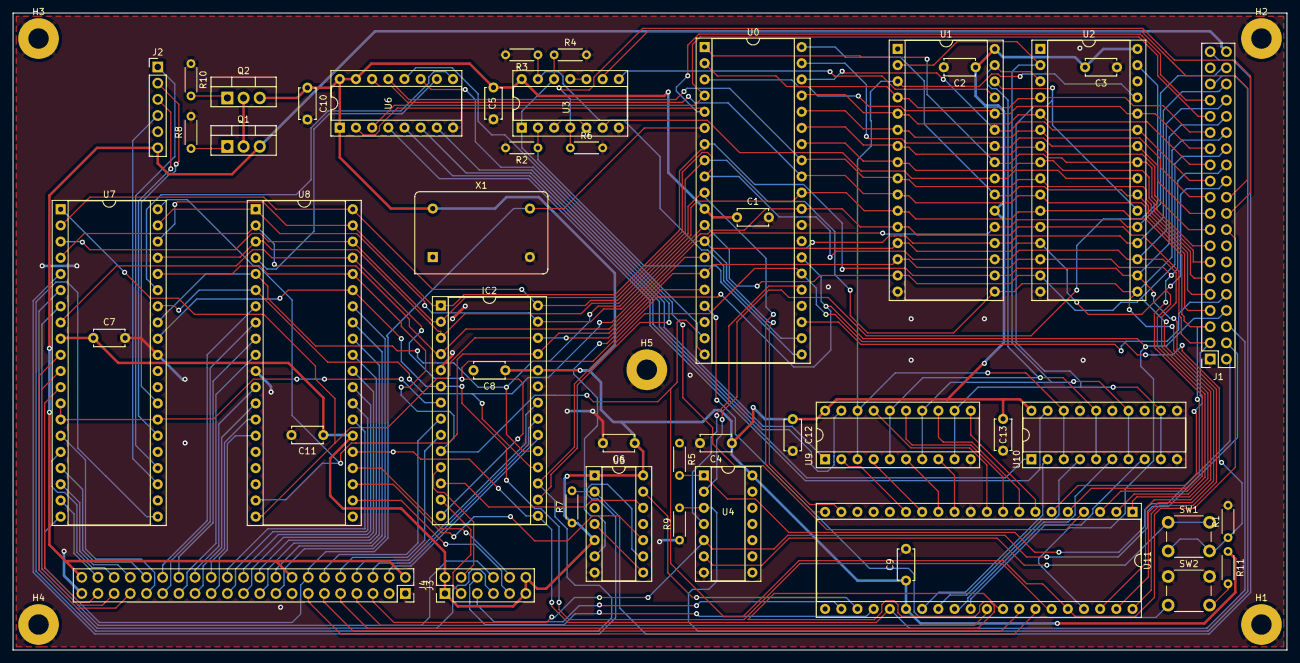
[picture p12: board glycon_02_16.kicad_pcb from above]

Board: 2 copper layers, 200.0 x 100.0 mm, 51 parts (0 on the bottom side), 129 nets.

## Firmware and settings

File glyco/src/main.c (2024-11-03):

#include "pinout.h"
#include "serial.h"
#include "flash.h"
#include "bus.h"

#include "common/glycon.h"
#include "common/binary_debug_protocol.h"

#include <stdint.h>
#include <stddef.h>
#include <stdbool.h>

#include <avr/interrupt.h>
#include <util/delay.h>

// Read an address from a BDBP data buffer.
gly_addr_t pkt_read_addr(uint8_t** data_ptr) {
    uint8_t* data = *data_ptr;
    gly_addr_t a = *data++;
    gly_addr_t b = *data++;
    gly_addr_t c = *data++;
    *data_ptr = data;
    return (c << 16) | (b << 8) | a;
}

// Try to acquire the Z80's bus. If that fails, return false,
// and return an error status.
bool acquire_bus_or_fail() {
    enum bus_acquire_status status = bus_acquire();
    switch (status) {
        case BUS_ACQUIRE_SUCCESS:
            return true;
        case BUS_ACQUIRE_TIMEOUT:
            serial_write_u8(BDBP_STATUS_BUS_ACQUIRE_TIMEOUT);
            serial_write_u8(0);
            return false;
        case BUS_ACQUIRE_ACQUIRED:
            serial_write_u8(BDBP_STATUS_BUS_ALREADY_ACQUIRED);
            serial_write_u8(0);
            return false;
        default:
            __builtin_unreachable();
    }
}

// Handle CMD_WRITE: Write some data to memory.
void cmd_write(uint8_t* data, uint8_t* data_end) {
    if (!acquire_bus_or_fail())
        return;

    gly_addr_t address = pkt_read_addr(&data);
    bus_set_mode(BUS_MODE_WRITE_MEM);
    while (data != data_end) {
        bus_write(address++, *data++);
        bus_pulse_ram_write();
    }
    bus_release();

    serial_write_u8(BDBP_STATUS_SUCCESS);
    serial_write_u8(0);
}

// Handle CMD_READ: Read some data from ram- or rom.
void cmd_read(uint8_t* data, uint8_t* data_end) {
    if (!acquire_bus_or_fail())
        return;
    gly_addr_t address = pkt_read_addr(&data);
    uint8_t amt = *data++;

    serial_write_u8(BDBP_STATUS_SUCCESS);
    serial_write_u8(amt);

    bus_set_mode(BUS_MODE_READ_MEM);
    for (uint8_t i = 0; i < amt; ++i) {
        serial_write_u8(bus_read(address + i));
    }
    bus_release();
}

// Handle CMD_FLASH: Write some data to flash storage.
void cmd_flash(uint8_t* data, uint8_t* data_end) {
    if (!acquire_bus_or_fail())
        return;

    gly_addr_t address = pkt_read_addr(&data);
    while (data != data_end) {
        flash_byte_program(address++, *data++);
    }
    bus_release();

    serial_write_u8(BDBP_STATUS_SUCCESS);
    serial_write_u8(0);
}

// Handle CMD_FLASH_ID: Returns the flash's manufacterer and device identifiers.
void cmd_flash_id() {
    if (!acquire_bus_or_fail())
        return;

    uint8_t mfg, dev;
    flash_get_software_id(&mfg, &dev);
    bus_release();

    serial_write_u8(BDBP_STATUS_SUCCESS);
    serial_write_u8(2);
    serial_write_u8(mfg);
    serial_write_u8(dev);
}

// Handle CMD_ERASE_SECTOR: Erases a single flash sector.
void cmd_erase_sector(uint8_t* data, uint8_t* data_end) {
    if (!acquire_bus_or_fail())
        return;

    gly_addr_t address = pkt_read_addr(&data);
    flash_erase_sector(address);
    bus_release();

    serial_write_u8(BDBP_STATUS_SUCCESS);
    serial_write_u8(0);
}

// Handle CMD_ERASE_CHIP: Erases the entire flash chip.
void cmd_erase_chip() {
    if (!acquire_bus_or_fail())
        return;
    flash_erase_chip();
    bus_release();

    serial_write_u8(BDBP_STATUS_SUCCESS);
    serial_write_u8(0);
}

int main(void) {
    PINOUT_LED_DDR |= PINOUT_LED_MASK;

    PINOUT_BUSREQ_DDR |= PINOUT_BUSREQ_MASK;
    PINOUT_BUSREQ_PORT &= ~PINOUT_BUSREQ_MASK;

    PINOUT_BUSACK_DDR &= ~PINOUT_BUSACK_MASK;
    PINOUT_BUSACK_PORT &= ~PINOUT_BUSACK_MASK;

    PINOUT_RESET_DDR &= ~PINOUT_RESET_MASK;
    PINOUT_RESET_PORT &= ~PINOUT_RESET_MASK;

    PINOUT_M1_DDR &= ~PINOUT_M1_MASK;
    PINOUT_M1_PORT &= ~PINOUT_M1_MASK;

    PINOUT_IOREQ_DDR &= ~PINOUT_IOREQ_DDR;
    PINOUT_IOREQ_PORT &= ~PINOUT_IOREQ_MASK;

    //PINOUT_ADDR_A_PORT = 0x00;
    //PINOUT_ADDR_A_DDR = 0x00;

    serial_init();
    sei();

    while (1) {
        // Use led to indicate processing.
        PINOUT_LED_PORT &= ~PINOUT_LED_MASK;
        serial_wait_for_data();
        //PINOUT_LED_PORT |= PINOUT_LED_MASK;

        uint8_t cmd = serial_read_u8();
        uint8_t data_len = serial_poll_u8();

        uint8_t msg_data[BDBP_MAX_DATA_LENGTH];
        for (size_t i = 0; i < data_len; ++i) {
            msg_data[i] = serial_poll_u8();
        }

        switch (cmd) {
            case BDBP_CMD_PING:
                serial_write_u8(BDBP_STATUS_SUCCESS);
                serial_write_u8(0);
                break;
            case BDBP_CMD_WRITE:
                cmd_write(msg_data, msg_data + data_len);
                break;
            case BDBP_CMD_READ:
                cmd_read(msg_data, msg_data + data_len);
                break;
            case BDBP_CMD_WRITE_FLASH:
                cmd_flash(msg_data, msg_data + data_len);
                break;
            case BDBP_CMD_FLASH_ID:
                cmd_flash_id();
                break;
            case BDBP_CMD_ERASE_SECTOR:
                cmd_erase_sector(msg_data, msg_data + data_len);
                break;
            case BDBP_CMD_ERASE_CHIP:
                cmd_erase_chip();
                break;
            default:
                serial_write_u8(BDBP_STATUS_UNKNOWN_CMD);
                serial_write_u8(0);
                break;
        }
    }

    return 0;
}

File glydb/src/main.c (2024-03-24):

#include "connection.h"
#include "debugger.h"

#include <unistd.h>

#include <stdio.h>
#include <stdlib.h>
#include <string.h>

int main(int argc, char* argv[]) {
    const char* initial_port = NULL;
    for (int i = 1; i < argc; ++i) {
        const char* arg = argv[i];
        if (strcmp(arg, "-h") == 0 || strcmp(arg, "--help") == 0) {
            puts("usage: glydb [-h|--help] [port]");
            puts("options:");
            puts("-h, --help    Show this message and exit.");
            puts("[port]        Port to connect to, for example /dev/ttyUSB0.");
            return EXIT_SUCCESS;
        } else if (!initial_port) {
            initial_port = arg;
        } else {
            fprintf(stderr, "error: unexpected argument '%s'\n", arg);
        }
    }

    struct debugger dbg;
    debugger_init(&dbg, initial_port);
    debugger_repl(&dbg);
    debugger_deinit(&dbg);
    return EXIT_SUCCESS;
}

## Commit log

2021-07-26 Project setup & ye olde blinking led
2021-08-08 Datasheet + arduino pinout
2021-08-18 change arduino to z80 bridge pinout
2021-12-26 coproc: pin direction enum
2022-01-03 add mainboard electric schematic
    [glycon.kicad_pcb, glycon.kicad_sch]
2022-01-06 Also update the other commands
    There are still some bugs left to be worded out.
    [binary_debug_protocol.h, main.c]
2022-01-07 glyco: use PINx rather than PORTx for reading pin state
2022-01-07 glyco: inline pinout functions and fix timeouts
    [main.c]
2022-01-09 fix minor errors in schematic + add mem oe to arduino connection
    [glycon-B_Cu.gbr, glycon-B_Mask.gbr, glycon-B_Plakken.gbr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]
2022-01-09 edit U2(ROM) symbol in schematic
    [glycon.kicad_sch]
2022-01-13 add xor gates between coproc header and OE, ROM WE
    [glycon.kicad_pcb, glycon1.kicad_sch]
2022-01-16 connect busack and busrq
    [glycon.kicad_sch]
2022-01-19 minor schematic updates
    [glycon-B_Cu.gbr, glycon-B_Mask.gbr, glycon-B_Plakken.gbr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]
2022-01-24 add busrq and busack to pinout diagram
    [glycon.kicad_sch]
2022-01-27 expand schematic with IO devices/mainboard design
    [glycon.kicad_pcb, ioboard.kicad_sch]
2022-01-31 more schematic work
    [glycon.kicad_pcb, glycon.kicad_sch]
2022-02-03 more pcb work
    [glycon.kicad_pcb, glycon.kicad_sch]
2022-02-05 pcb design
    [glycon.kicad_pcb, glycon.kicad_sch]
2022-02-06 pcb work
    [glycon.kicad_pcb, glycon.kicad_sch]
2022-02-07 glyco: add some missing comments
    [main.c]
2022-02-13 finish pcb trace routing
    [glycon.kicad_pcb, glycon.kicad_sch]
2022-02-21 pcb refinement
    [glycon.kicad_pcb, glycon.kicad_sch]
2022-03-11 update mainboard schematic pdf and add ledmatrix project under doc
    [ledmatrix.kicad_pcb, ledmatrix.kicad_sch]
2022-03-28 add BOM
    [glycon.csv, ledmatrix.kicad_pcb, ledmatrix.kicad_sch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]
2022-03-29 rollback schematic file to kicad 6.0.4
    [glycon.kicad_pcb, glycon.kicad_sch, ioboard.kicad_sch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]
2022-03-29 update gerber plot files
    [glycon.kicad_pcb, test.kicad_pcb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]
2022-04-13 update pinout schematic + add old revision of board under 'glycon_rev1.0'
    [glycon.kicad_pcb, glycon_02_16.csv, glycon_02_16.kicad_pcb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]
2022-04-27 add missing A8 pin to pinout diagram
    [glycon.kicad_sch]
2022-05-03 schematic fixes
    [glycon.kicad_pcb, glycon.kicad_sch]
2022-05-08 More schematic fixes
    [glycon.kicad_pcb, glycon.kicad_sch]
2022-06-03 Convert pcb file to old kicad format
    [glycon.kicad_pcb, glycon.kicad_sch, glycon_02_16.kicad_sch]
2022-06-03 ok so now they should be readable by kicad stable
    [glycon.kicad_pcb, glycon.kicad_sch]
2022-09-17 add resistor packs
    [glycon.kicad_pcb, glycon.kicad_sch]
2022-09-17 add resistor pack to pcb
    [glycon.kicad_pcb, glycon.kicad_sch]
2023-12-03 update schematic
2023-12-17 switch bus IO on coprocessor to input after bus acquisition. Also modify the test assembly a bit.
2024-03-17 cleaned up schematic
    [glycon.csv, glycon.kicad_pcb, glycon.kicad_sch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]
2024-03-17 create pdf of revised schematic
    [glycon.kicad_sch]
2024-03-17 new PCB layout and initial routing
    [glycon.kicad_pcb, glycon.kicad_sch]
2024-03-29 kicad work
    [glycon.kicad_pcb, glycon.kicad_sch]
2024-04-01 More pcb progress
    [glycon.kicad_pcb, glycon.kicad_sch]
2024-05-20 almost finalized new pcb design
    [glycon-B_Cu.gbl, glycon-B_Mask.gbs, glycon-B_Plakken.gbp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]
